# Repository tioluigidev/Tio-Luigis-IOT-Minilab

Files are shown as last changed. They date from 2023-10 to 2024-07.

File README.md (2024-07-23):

# My IOT Minilab

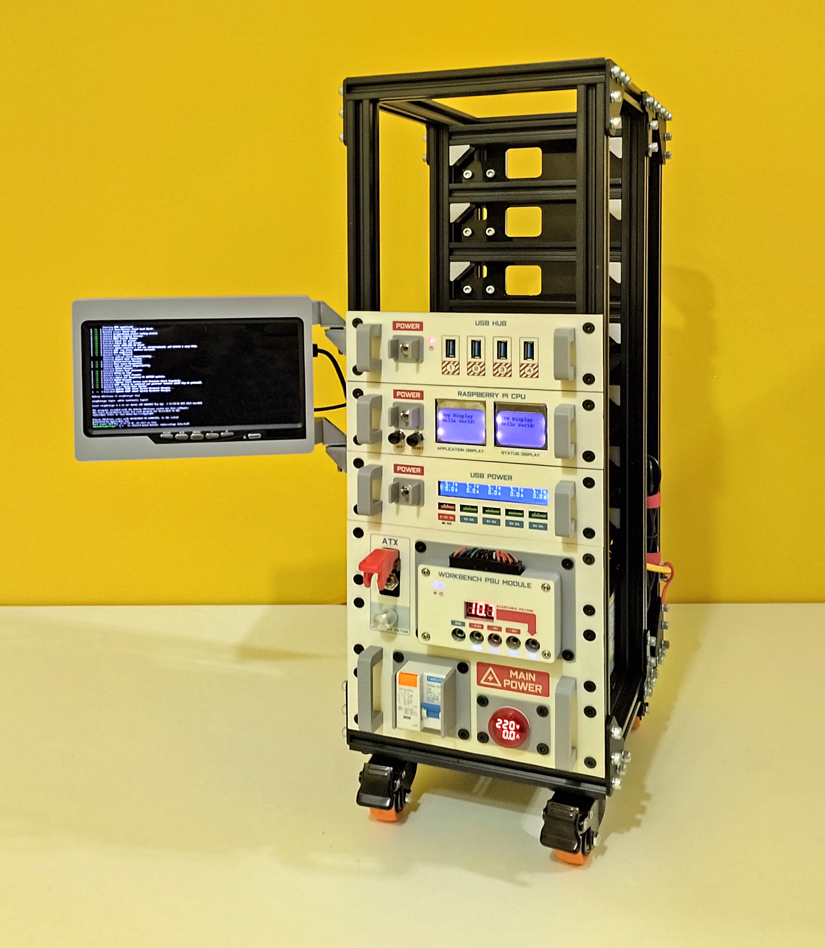
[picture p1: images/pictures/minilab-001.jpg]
Tio Luigi´s IOT Minilab


## Description

This is my IoT minilab. A platform to make projects and experiments involving the internet of things and electronics.
This is an open source project and you will find all necessary information to reproduce this project, modify it, contribute with it, etc.

I hope you enjoy it :)

## Features

- Rack mounted in a "maker style", so you can easily modify it, extend it, create new modules, etc.
- You can also use it as a workbench tool.
- ATX PSU (3.3V, 5V, 12V and adjustable voltage) for the built-in modules and for the workbench experiments and tests.
- USB PSU/charger, for those devices that uses USB power cord, inside the rack or on the workbench.
- Small CPU module with USB hub for conecting to your IOT devices (yes yes, inside the rack or on the workbench).
- It uses ready-made parts, so you don´t have to make printed circuit boards!

## Structure and Modules

|Picture|Documentation|
|---|---|
|USB Hub Module|[USB Hub Module](readme-module-usbhub.md)|
|Raspberry Pi CPU Module|[Raspberry Pi CPU Module](readme-module-rpicpu.md)|
|USB Power Module|[USB Power Module](readme-module-usbpower.md)|
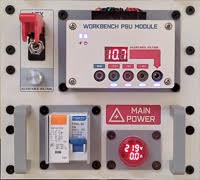
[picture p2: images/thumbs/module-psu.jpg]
PSU Module
||[PSU Module](readme-module-psu.md)|
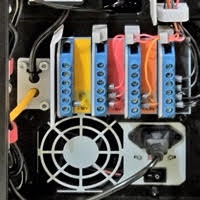
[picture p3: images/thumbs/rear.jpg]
Rear
||[Rear](readme-rear.md)|
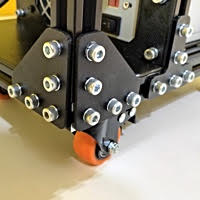
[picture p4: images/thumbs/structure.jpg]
Structure
||[Structure](readme-structure.md)|

## Extras

Some optional stuffs that may be usefull:

|Picture|Documentation|
|---|---|
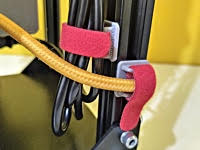
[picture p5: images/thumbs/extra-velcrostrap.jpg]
Support for velcro strap
||[Support for velcro strap](readme-extra-velcrostrap.md)|
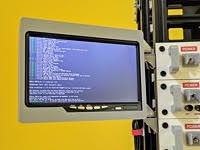
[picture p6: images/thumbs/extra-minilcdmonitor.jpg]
Mini LCD monitor
||[Mini LCD monitor](readme-extra-minilcdmonitor.md)|

## Blender Project

This minilab was designed on Blender 3D software. You can download the Blender project file [here](project/minilab.blend).
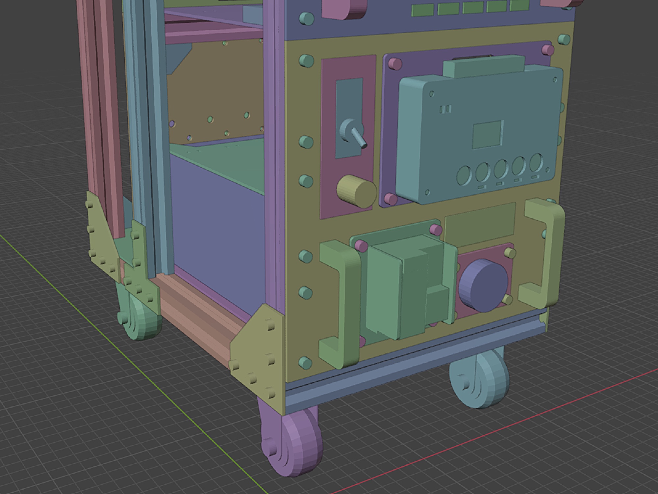
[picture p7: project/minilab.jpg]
Project


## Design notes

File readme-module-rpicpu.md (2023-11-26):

# Raspberry Pi CPU Module

## Description

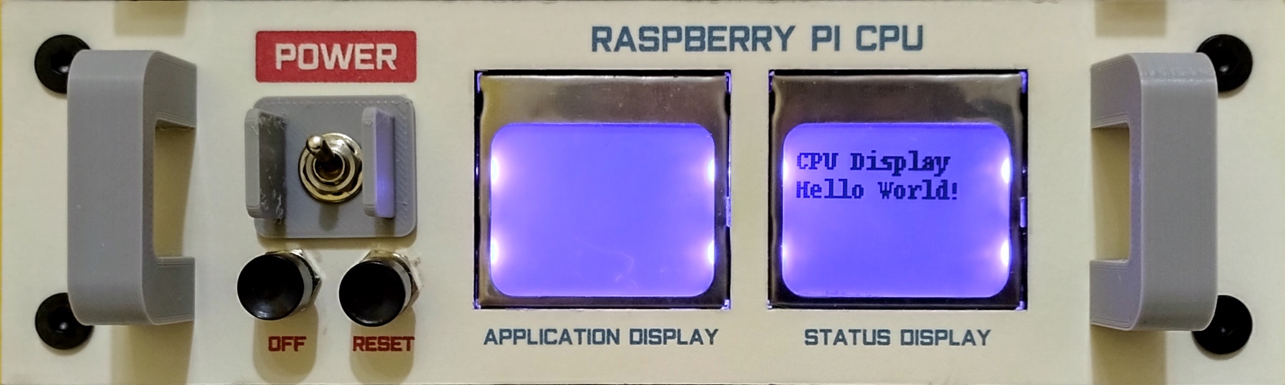
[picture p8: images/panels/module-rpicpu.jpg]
Raspberry Pi CPU Module


This module is "a brain" for the minilab. I connected 2 Nokia 5110 displays to the Raspberry Pi 4 SPI interface. One for system status and another one for application informations. I decided to use the Ultra Thin Ice Tower Cooler, because in addition to the 2 power wires, it also has a third wire through which the fan speed can be measured. I also decided to use a 400 points breadboard, for a small hacking space.

There is also two push buttons: one for RESET and another one for OFF functions. The pressing of theese buttons is handled by the "monitor.py" software in "src" directory.  

## Schematics

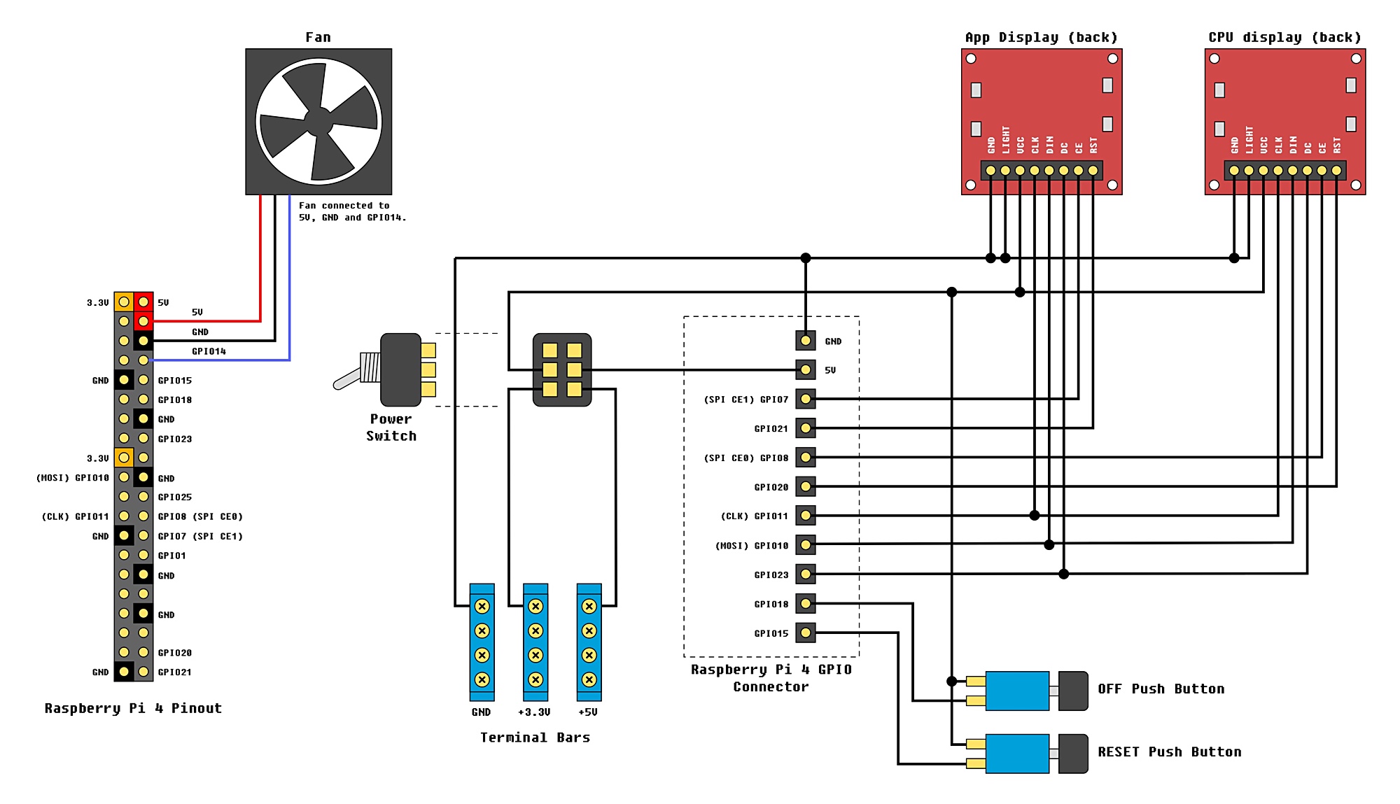
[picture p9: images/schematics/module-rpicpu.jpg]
Raspberry Pi CPU Module Schematics


For the LCD backlight control pins, you have three choices:
- Leave then unconnected, so the backlights will always be turned off,
- Connect then to the GND, so the backlights will always be turned on,
- Connect then to the GPIO 1 and 25 pins (like me), so you can control via software when turn on or off the backlights.

## 3D Printed Parts

To make the 3d printed parts, I used an Creality Ender 3 similar 3d printer. Some parts I printed with 0.8mm nozzle, just for speed gain (where aesthetics were not so important). For all the other parts, I used 0.4mm nozzle. The original editable Blender files are also included in the "3dprint" directory.

Caption|File|Prints|Nozzle|Supports|Description|
|---|---|---|---|---|---|
| 1|[rpicpu.base.stl](./3dprint/module-rpicpu/rpicpu.base.stl)|1|0.8|No|Module base.|
| 2|[rpicpu.innersupport.left.stl](./3dprint/module-rpicpu/rpicpu.innersupport.left.stl)|1|0.4|Maybe|Left inner support.|
| 3|[rpicpu.innersupport.right.stl](./3dprint/module-rpicpu/rpicpu.innersupport.right.stl)|1|0.4|Maybe|Right inner support.|
| 4|[rpicpu.panel.lcdsupport.stl](./3dprint/module-rpicpu/rpicpu.panel.lcdsupport.stl) |1|0.4|Yes|Inner support for LCD modules.|
| 5|[rpicpu.panel.front.stl](./3dprint/module-rpicpu/rpicpu.panel.front.stl) |1|0.8|Yes|Front panel for the module.|
| 6|[rpicpu.panel.powerpanel.stl](./3dprint/module-rpicpu/rpicpu.panel.powerpanel.stl)|1|0.4|No|Module switch protector.|
| 7|[rpicpu.panel.handler.stl](./3dprint/module-rpicpu/rpicpu.panel.handler.stl)|2|0.4|Maybe|Module handlers.|

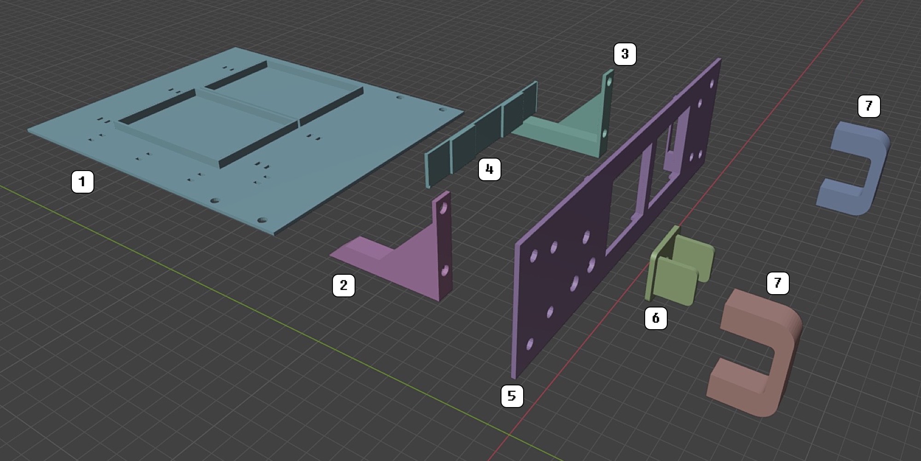
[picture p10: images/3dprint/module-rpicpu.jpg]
3D Printed Parts for Raspberry Pi CPU Module


## Paper Printed Parts

I used inkjet printer and an off-white 180g/m2 paper to make the front panel of the modules. In Brazil, this paper is known as "Color Plus 180g Marfim". To create these files, I used a software called "Graphics", that works on Mac. The original editable Graphics file for each print is in the "print" directory.

|File|Description|
|---|---|
|[print.rpicpu.panel.pdf](./print/print.rpicpu.panel.pdf)|Raspberry Pi CPU Module front panel.|

## Software

In "src" directory there is a small software in Python language, that I used to start up the LCDs and display some "Hello World" test message. To install the requirements for this software, just follow the following steps:

```bash
pip install RPi.GPIO
pip install Adafruit_GPIO
pip install pillow

sudo apt-get install git
git clone https://github.com/adafruit/Adafruit_Nokia_LCD.git
cd Adafruit_Nokia_LCD
sudo python setup.py install
cd ..

python src/monitor.py
```
PS: Don´t forget to activate the SPI interface in the Raspberry configuration tool ( raspi-config -> Interface Options -> P4 SPI -> Enable it).

If you want that this software is automatically executed on boot, just modify the "/etc/rc.local" adding the following line, where "path-to-src" is the complete path to the src/monitor.py file:

```bash
python path-to-src/monitor.py
```

## Shopping List

Qty|Description|
|---|---|
| 1 | Raspberry Pi board.|
| 1 | Ice Cube Cooler for Raspberry Pi (see Pictures). I found mine in [this link](https://pt.aliexpress.com/item/1005004647625855.html).|
| 2 | Nokia 5110 LCD displays (see Pictures).|
| 1 | 400 points breadboard (see Pictures).|
| 1 | Kit with 40 female-male jumpers 10cm min. length (see pictures).|
| 1 |Margirius lever microswitch bipolar with 2 positions (on/off).|
| 1 meter|0.30mm black wire.|
| 1 meter|0.30mm red wire.|
| 1 meter|0.30mm orange wire.|
| 1 meter|0.30mm red wire.|
| 1 meter|0.30mm any color wire, to connect the OFF push botton to the breadboard.|
| 1 meter|0.30mm any color wire, to connect the RESET push botton to the breadboard.|
| 15 ~ 20|Nylon cable ties.|
| 4 |Allen Bolt M5x6 Cylindrical Head.|
| 8 |Allen Bolt M5x6 Flat Head.|
| 4 |Hammer Nut M5.|
| 1 |Thick paper sheet (if you want to print the panel).|
| ~ 125g | PLA 3D print filament.|

## Nuts and Bolts

Picture|Description|
|---|---|
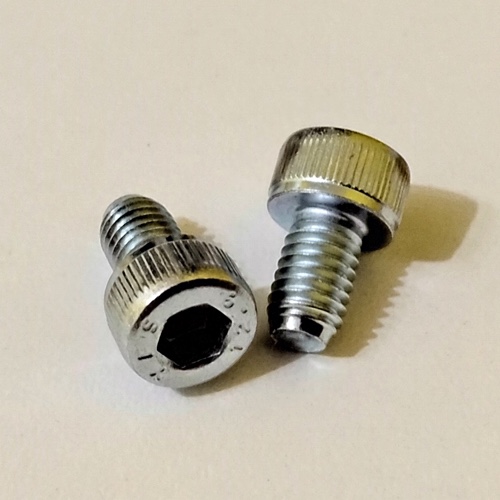
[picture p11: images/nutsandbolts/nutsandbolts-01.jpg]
||Allen Bolt M5x6 Cylindrical Head (5mm on diameter, 6mm on length)|
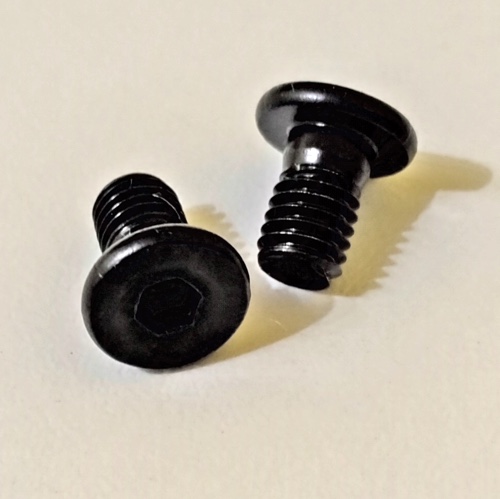
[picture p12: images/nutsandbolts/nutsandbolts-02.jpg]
||Allen Bolt M5x6 Flat Head (5mm on diameter, 6mm on length)|
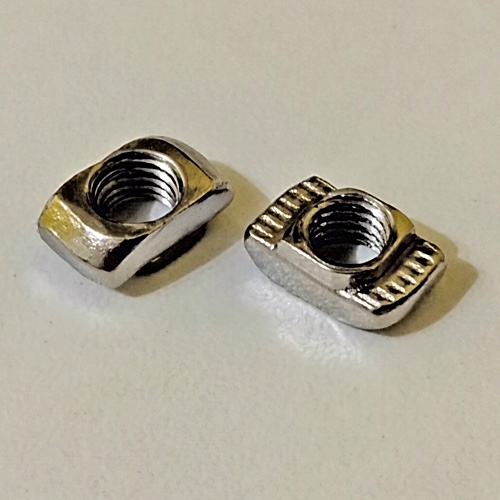
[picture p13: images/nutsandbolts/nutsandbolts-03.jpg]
||Hammer Nut M5 (for 5mm diameter bolts)|

## Pictures

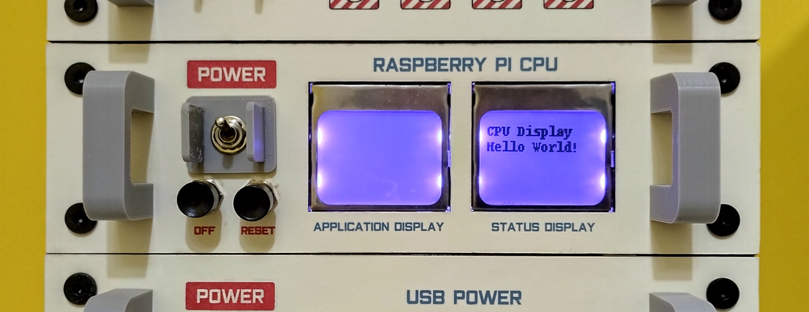
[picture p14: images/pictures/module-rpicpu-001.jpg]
Raspberry Pi CPU Module (panel)


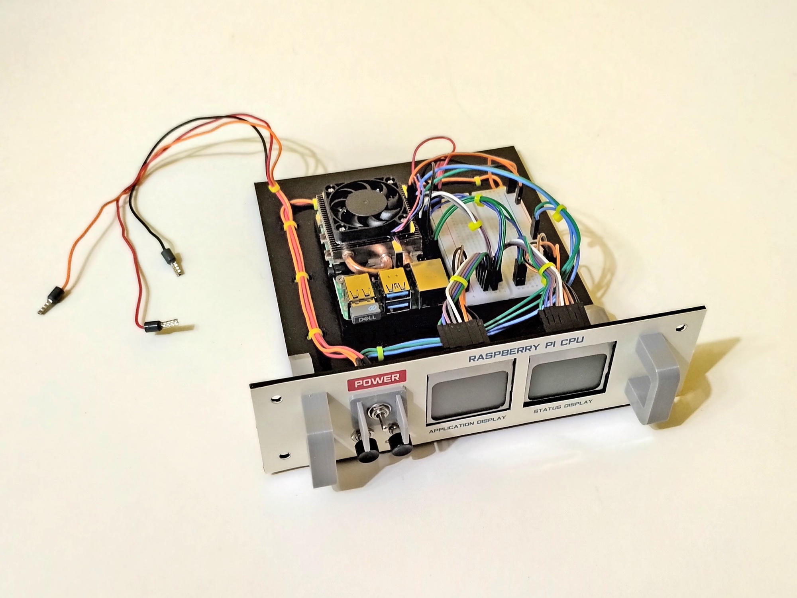
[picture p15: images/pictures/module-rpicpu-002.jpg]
Raspberry Pi CPU Module (whole)


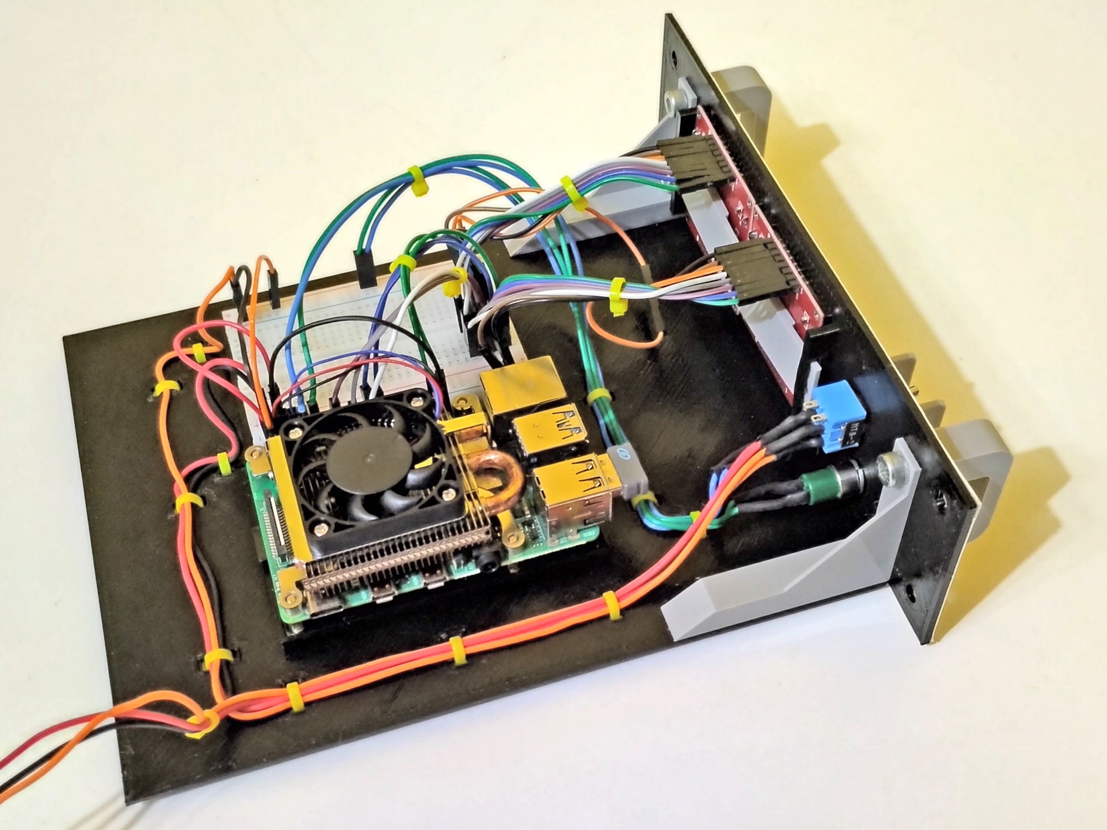
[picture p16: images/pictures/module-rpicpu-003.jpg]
Raspberry Pi CPU Module (left)


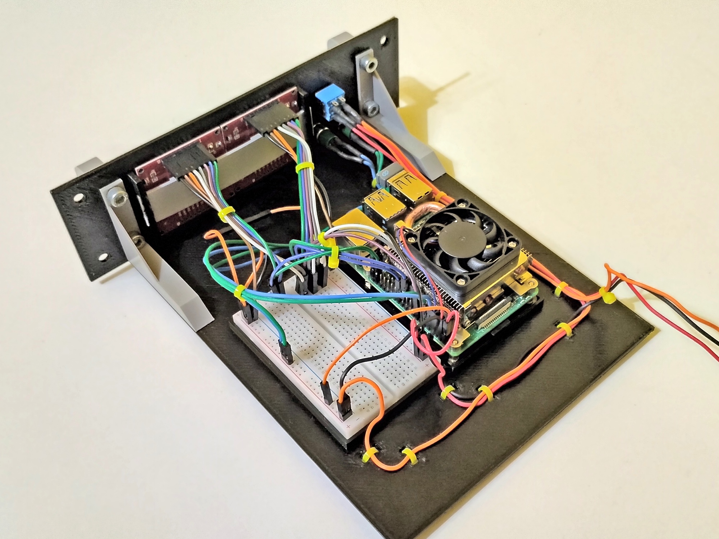
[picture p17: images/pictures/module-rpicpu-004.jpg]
Raspberry Pi CPU (right)


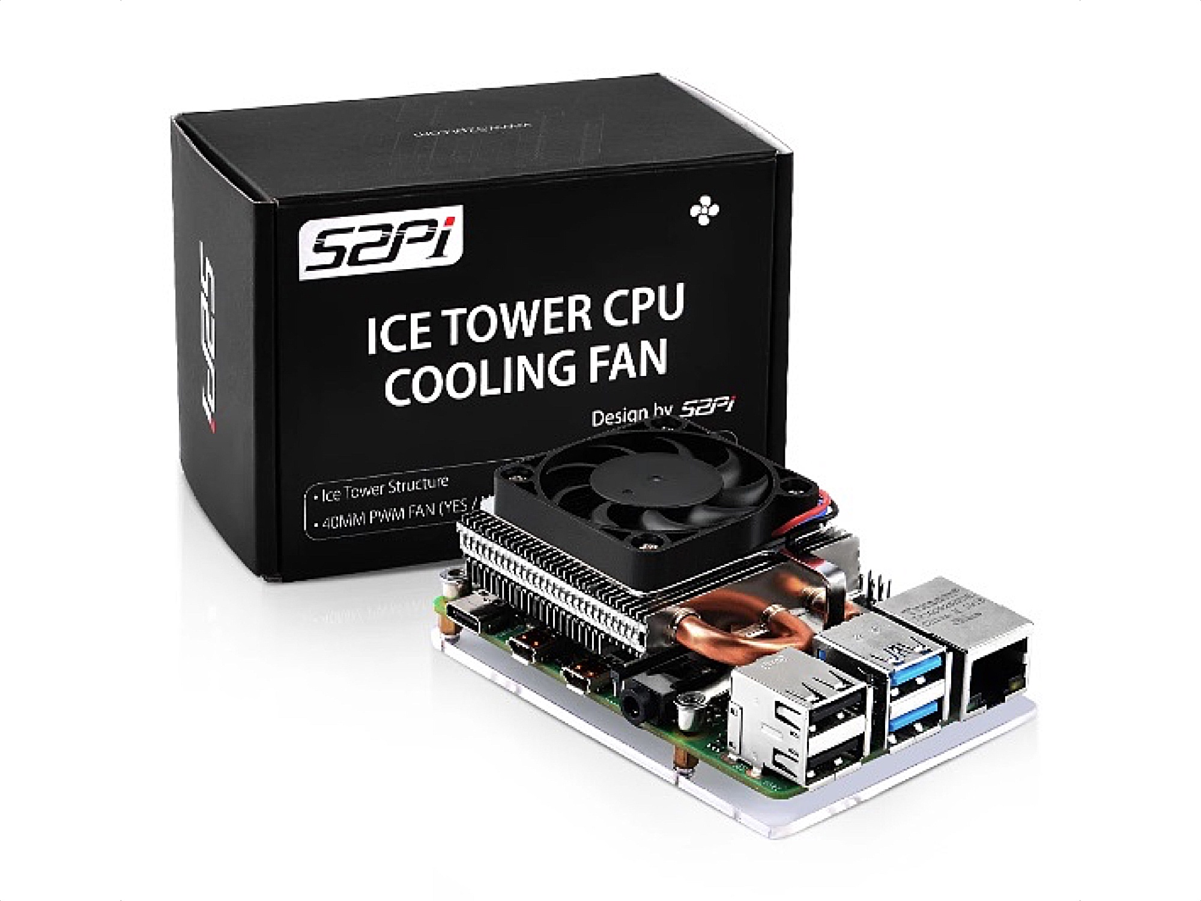
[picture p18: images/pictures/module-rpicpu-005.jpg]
Raspberry Pi CPU (Raspberry Pi and Cooler)


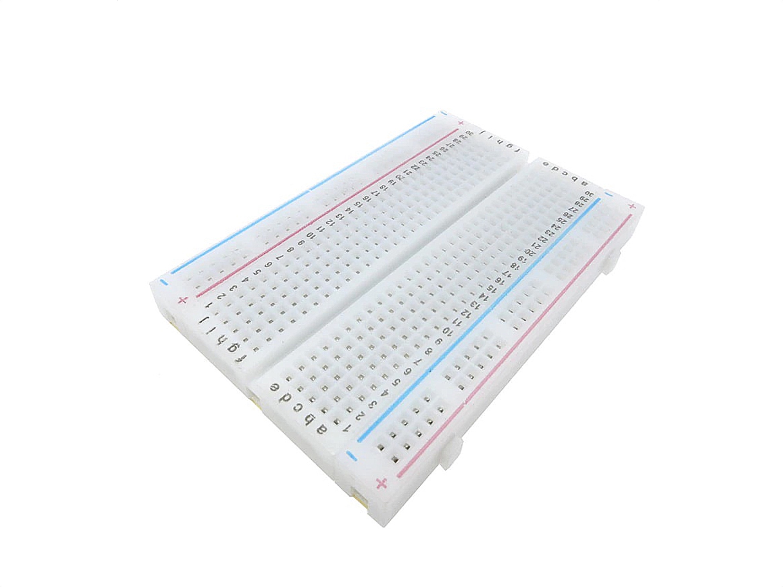
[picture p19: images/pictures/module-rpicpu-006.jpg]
400 Points Breadboard


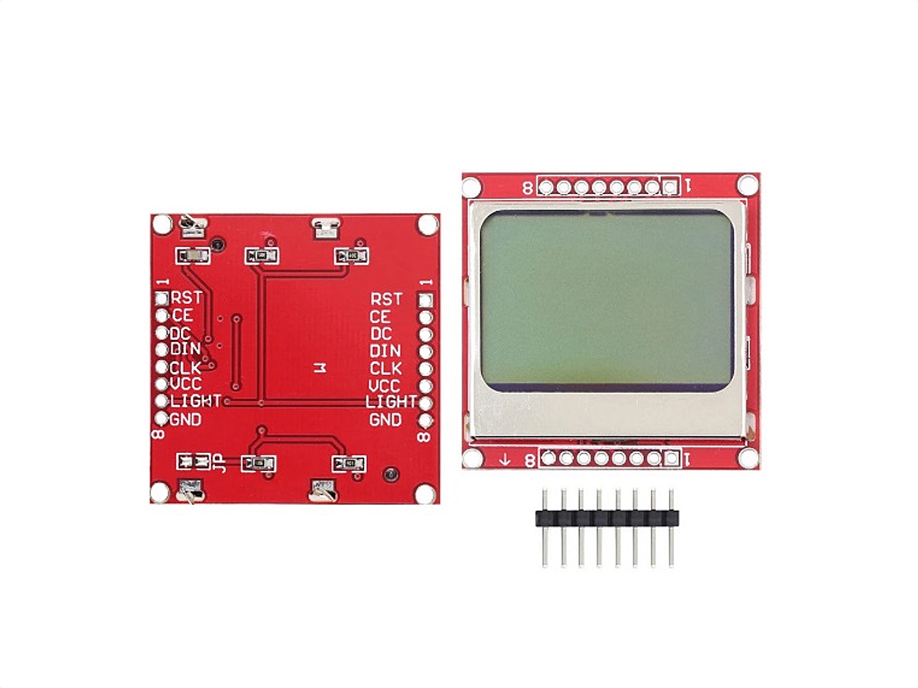
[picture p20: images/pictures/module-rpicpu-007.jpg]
Nokia 5110 LCD Display


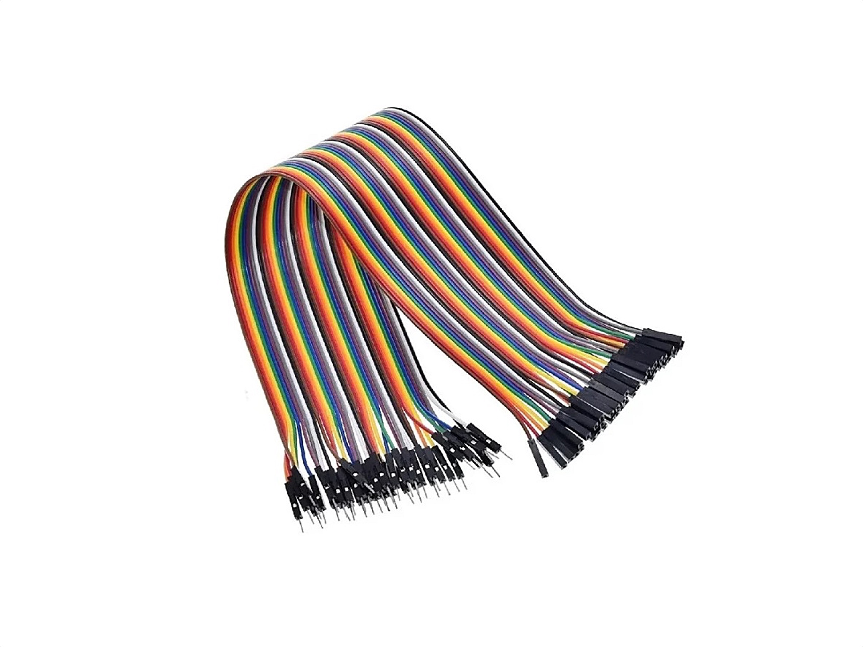
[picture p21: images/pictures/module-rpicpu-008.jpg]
Kit 40 jumpers female-male (min. 10 cm)


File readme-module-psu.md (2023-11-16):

# PSU Module

## Description

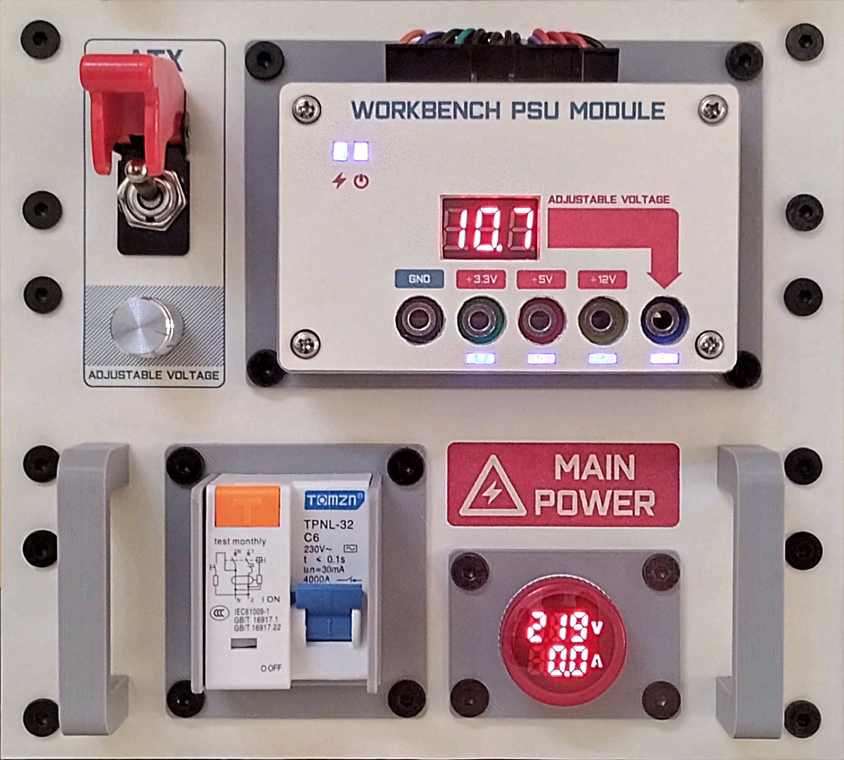
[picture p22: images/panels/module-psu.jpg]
PSU Module


The PSU (Power Supply Unity) Module is responsible to power up all the system. It´s the only module designed to be fixed (not so easily removable). The main power switch is a 6A circuit breaker. In my project, I used a circuit breaker with residual current protection, to prevent electrical shock. There is also a power meter with a double display, for voltage and current measuring. The main power line ends in a power strip, with 4 electrical outlets.

Connected to this power strip, there is an ATX Power Supply. I used a 250W retail model. This ATX PSU powers the 4 terminal bars at the rear part of the rack. These terminal bars are used to power all the small circuits and IOT devices that uses 3.3V, 5V and/or 12V power.

The ATX PSU also powers a Workbench Module, used to provide voltage to workbench projects and experiments. Connected to this module, there is a Power Switch, that starts up the ATX PSU and a potentiometer for adustable voltage output, provided by the workbench module too. 

## Schematics

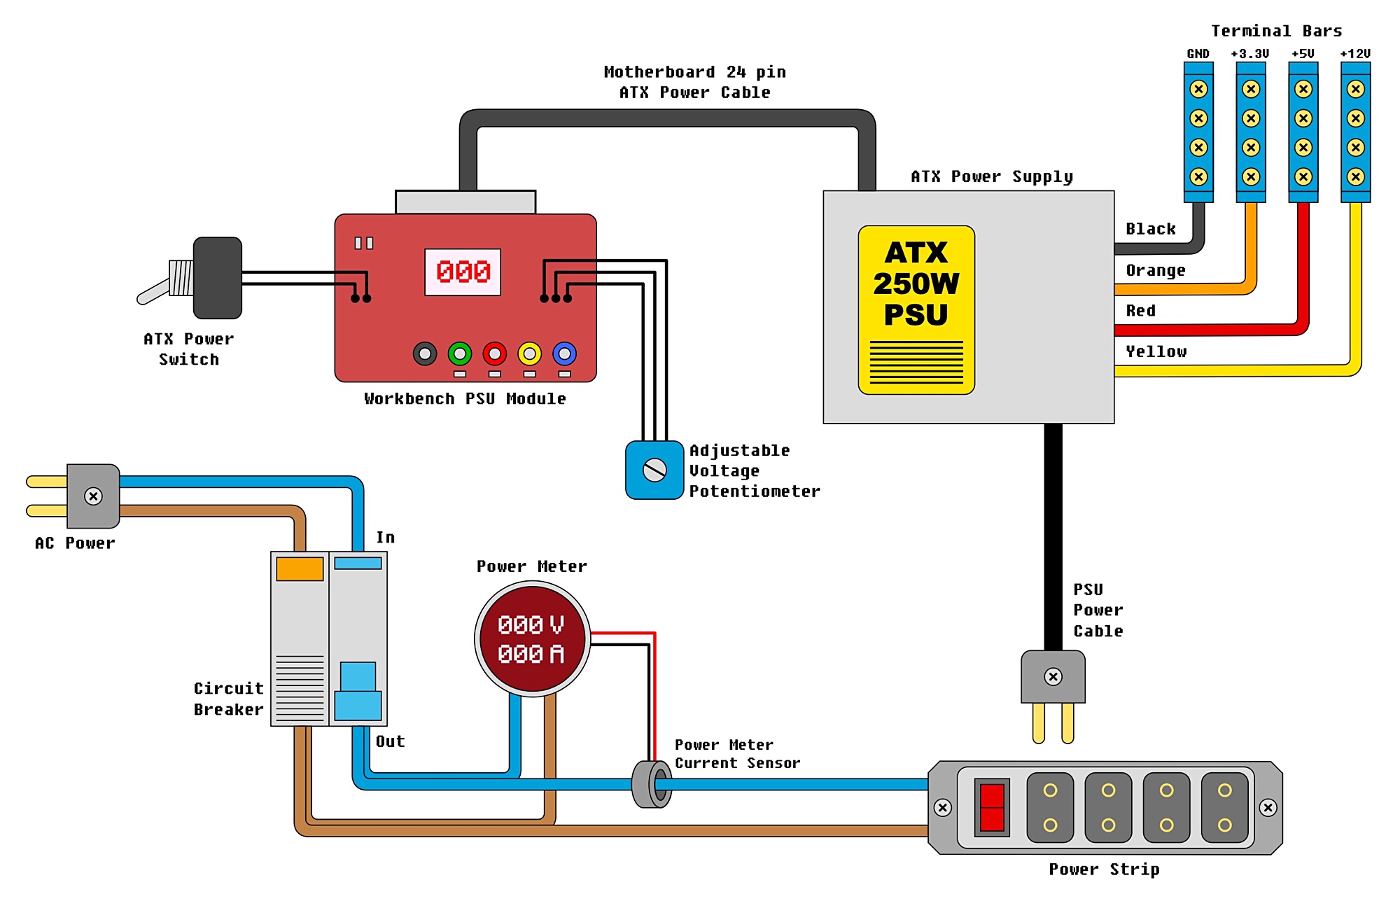
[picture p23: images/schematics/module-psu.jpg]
PSU Module Schematics


## 3D Printed Parts

To make the 3d printed parts, I used an Creality Ender 3 similar 3d printer. Some parts I printed with 0.8mm nozzle, just for speed gain (where aesthetics were not so important). For all the other parts, I used 0.4mm nozzle. The original editable Blender files are also included in the "3dprint" directory.

Caption|File|Prints|Nozzle|Supports|Description|
|---|---|---|---|---|---|
| 1|[psu.base.stl](./3dprint/module-psu/psu.base.stl)|1|0.8|No|Module base, wich supports the ATX PSU.|
| 2|[psu.cableguide.stl](./3dprint/module-psu/psu.cableguide.stl)|1|0.8|Maybe|Inner cable guide. I didn't use supports.|
| 3|[psu.circuitbreakersupport.stl](./3dprint/module-psu/psu.circuitbreakersupport.stl)|1|0.8|No|Circuit breaker support. Necessary to keep the circuit breaker in the correct position and tight attached to the front panel.|
| 4|[psu.potentiometersupport.stl](./3dprint/module-psu/psu.panel.potentiometersupport.stl) |1|0.4|Yes|Adjustable voltage potentiometer support. Necessary to keep the potentiometer in the correct position and tight attached to the front panel.|
| 5|[psu.panel.front.stl](./3dprint/module-psu/psu.panel.front.stl)                 |1|0.8|No|Front panel, where all other panel components are attached to.|
| 6|[psu.panel.modulecover1.stl](./3dprint/module-psu/psu.panel.modulecover1.stl)   |1|0.4|No|Workbench module base.|
| 7|[psu.panel.modulecover2.stl](./3dprint/module-psu/psu.panel.modulecover2.stl)   |1|0.4|No|Workbench module cover.|
| 8|[psu.panel.circuitbreakerpanel.stl](./3dprint/module-psu/psu.panel.circuitbreakerpanel.stl)|1|0.4|No|Circuit breaker front protector.|
| 9|[psu.panel.meterpanel.stl](./3dprint/module-psu/psu.panel.meterpanel.stl) |1|0.4|No|Power meter front base.|
|10|[psu.panel.handler.stl](./3dprint/module-psu/psu.panel.handler.stl)       |2|0.4|Maybe|Left and right module handler. I used supports.|

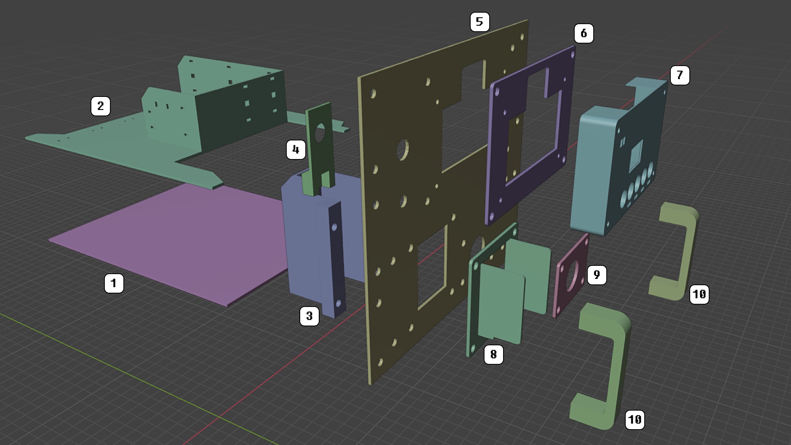
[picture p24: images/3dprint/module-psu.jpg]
3D Printed Parts for PSU Module


## Paper Printed Parts

I used inkjet printer and an off-white 180g/m2 paper to make the front panel of the modules. In Brazil, this paper is known as "Color Plus 180g Marfim". To create these files, I used a software called "Graphics", that works on Mac. The original editable Graphics file for each print is in the "print" directory.

|File|Description|
|---|---|
|[print.psu.panel.pdf](./print/print.psu.panel.pdf)|PSU Module front panel.|
|[print.psu.panel.module.pdf](./print/print.psu.panel.module.pdf)|Workbench PSU Module panel.|
|[print.rear.labels.pdf](./print/print.rear.labels.pdf)|Rear Terminal Bars labels.|

## Shopping List

Qty|Description|
|---|---|
| 1|ATX power supply. 250W is far enough.|
| 1|ATX PSU breakout module (see pictures).|
| 1|Power strip with 4 outlets.|
| 1|6A circuit breaker. I uded a Tomzn C6 model.|
| 1|Voltage and current meter (see pictures).|
| 4|Terminal bars with 6 terminals each. I found mine in [this link](https://pt.aliexpress.com/item/1005004186912405.html).
| 1|Power plug.|
| 1|Power Switch. I used a margirius switch with protection cover.|
| 1|100K linear potentiometer (only if your breakout module came with a logarithmic one).|
| 1 meter|2.5mm blue wire, for internal wiring. Maybe you don´t need this, if you use the power strip cord.|
| 1 meter|2.5mm brown wire, for internal wiring. Maybe you don´t need this, if you use the power strip cord.|
| 1 ~ 2 meters|0.30mm wire, for connect the ATX Power Switch and the Potentiometer to the ATX breakout module.|
| 1 ~ 2 meters|Main power cord with plug.|
| 20 ~ 30|Nylon cable ties.|
|  8|Allen Bolt M5x6 Cylindrical Head.|
| 24|Allen Bolt M5x6 Flat Head.|
|  4|Spring Washer 5mm.|
| 12|Hammer Nut M5.|
|  8|Allen Bolt M3x20 with washer and pressure bolt.|
| ~ 320g | PLA 3D print filament. |

## Nuts and Bolts

Picture|Description|
|---|---|
|PSU Module|Allen Bolt M5x6 Cylindrical Head (5mm on diameter, 6mm on length)|
|PSU Module|Allen Bolt M5x6 Flat Head (5mm on diameter, 6mm on length)|
|PSU Module|Hammer Nut M5 (for 5mm diameter bolts)|
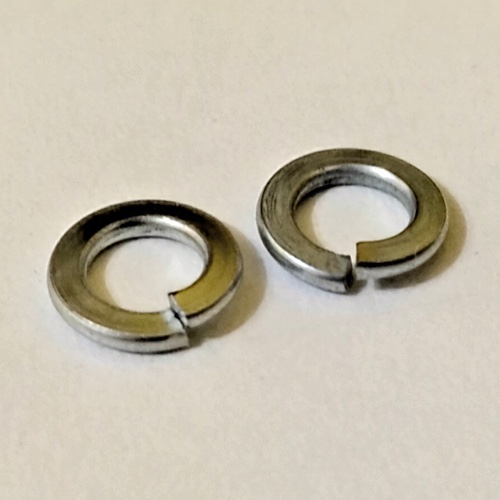
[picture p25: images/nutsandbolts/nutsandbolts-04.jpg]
||Spring Washer 5mm|
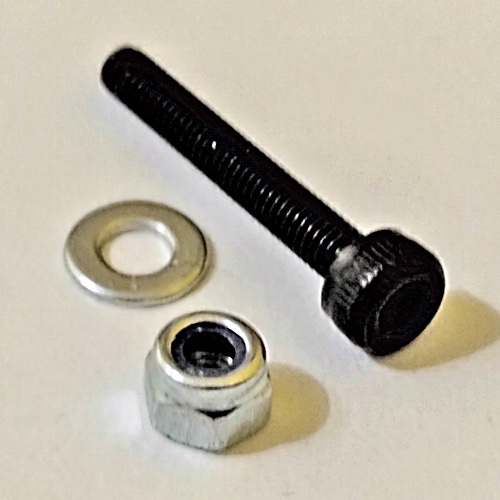
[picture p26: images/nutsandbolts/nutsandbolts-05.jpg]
||Allen Bolt M3x20 (3mm on diameter, 20mm on lenght) with washer and pressure bolt.|

## Pictures

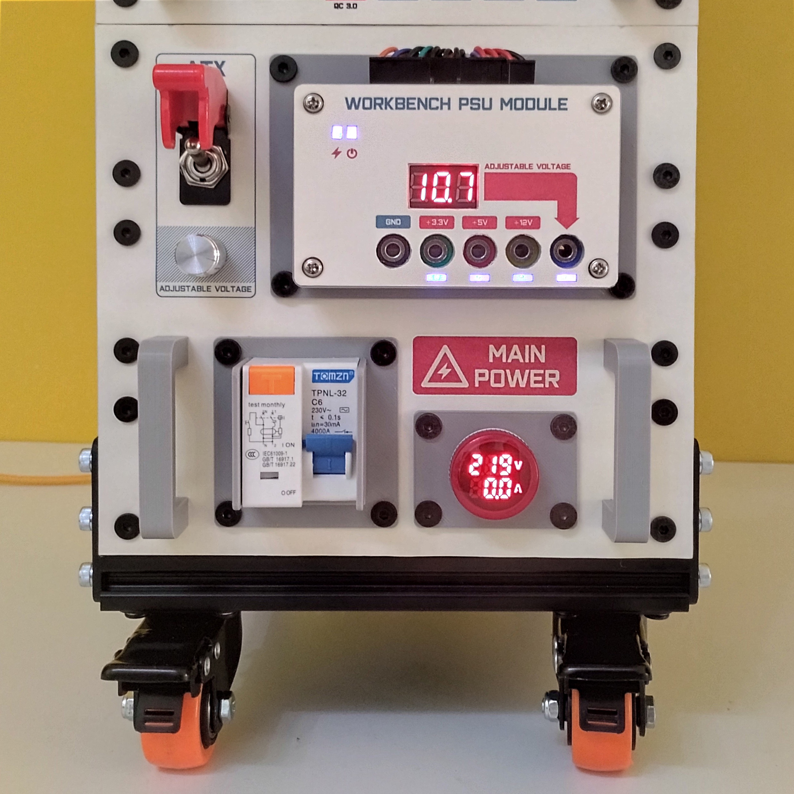
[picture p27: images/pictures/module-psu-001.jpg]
PSU Module


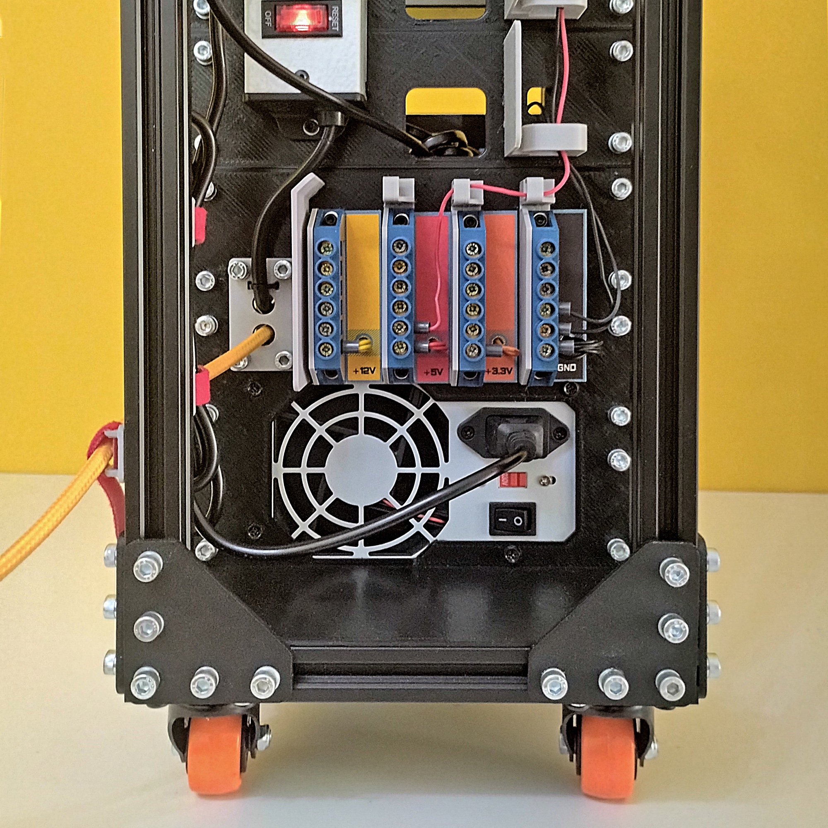
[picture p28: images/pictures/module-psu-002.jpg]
PSU Module (rear)


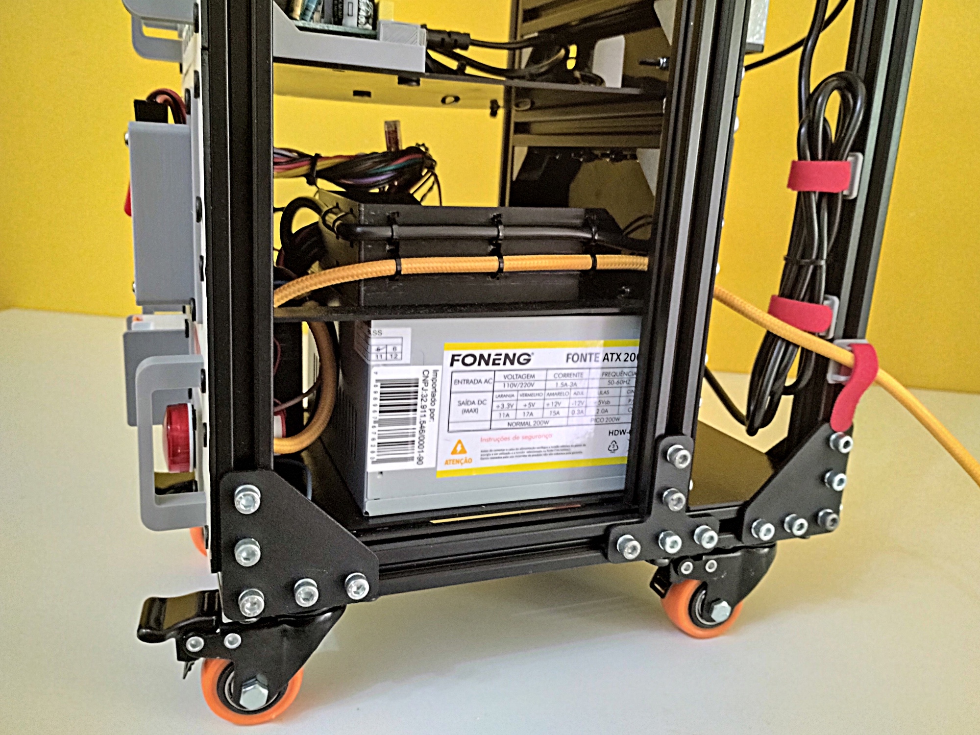
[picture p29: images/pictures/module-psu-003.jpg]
PSU Module (inside right)


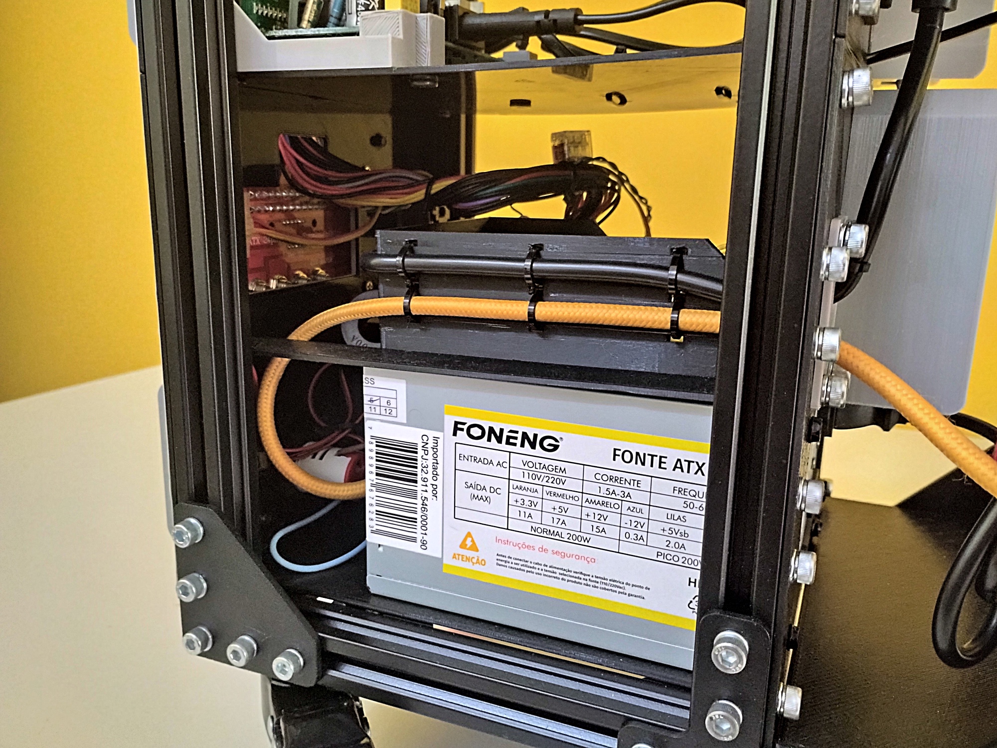
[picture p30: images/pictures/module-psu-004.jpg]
PSU Module (inside right)


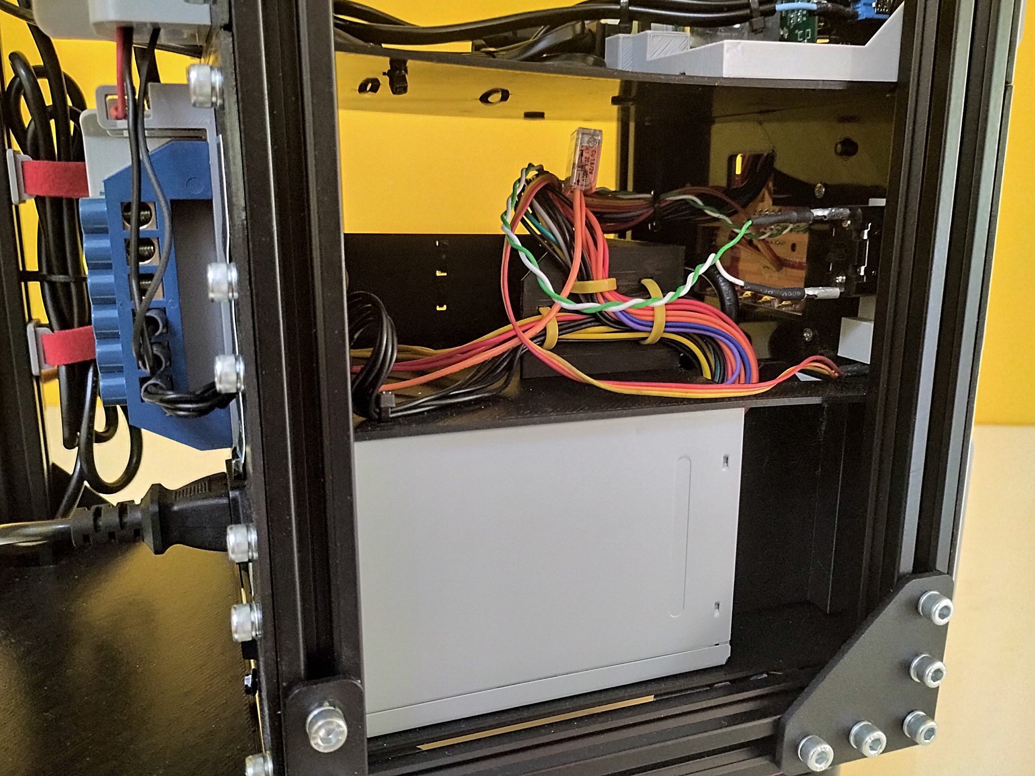
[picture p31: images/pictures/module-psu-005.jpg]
PSU Module (inside left)


PSU Module (ATX Breakout Module)

ATX Breakout Module, as sold

Circuit Breaker

Meter

Terminal Bar

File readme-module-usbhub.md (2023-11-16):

# USB Hub Module

## Description

PSU Module

This module is intended to provide USB connectivity from the CPU to other devices. These devices may be inside the minilab or outside (on a workbench, for example). I did´t built it from stratch. Instead, I used an USB hub with 4 ports. I chose this model because it has the USB ports well away from each other, and this is an important detail for a project I want to do in a near future.

## Schematics

USB Hub Module Schematics

## 3D Printed Parts

To make the 3d printed parts, I used an Creality Ender 3 similar 3d printer. Some parts I printed with 0.8mm nozzle, just for speed gain (where aesthetics were not so important). For all the other parts, I used 0.4mm nozzle. The original editable Blender files are also included in the "3dprint" directory.

Caption|File|Prints|Nozzle|Supports|Description|
|---|---|---|---|---|---|
| 1|[usbhub.base.stl](./3dprint/module-usbhub/usbhub.base.stl)|1|0.8|No|Module base.|
| 2|[usbhub.innersupport.left.stl](./3dprint/module-usbhub/usbhub.innersupport.left.stl)|1|0.4|Maybe|Left inner support for the usb hub circuit.|
| 3|[usbhub.innersupport.right.stl](./3dprint/module-usbhub/usbhub.innersupport.right.stl)|1|0.4|Maybe|Right inner support for the usb hub circuit.|
| 4|[usbhub.innersupport.middle.stl](./3dprint/module-usbhub/usbhub.innersupport.middle.stl) |1|0.4|No|Main inner support for the usb hub circuit.|
| 5|[usbhub.panel.front.stl](./3dprint/module-usbhub/usbhub.panel.front.stl) |1|0.8|No|Front panel for the module.|
| 6|[usbhub.panel.powerpanel.stl](./3dprint/module-usbhub/usbhub.panel.powerpanel.stl)|1|0.4|No|Module switch protector.|
| 7|[usbhub.panel.handler.stl](./3dprint/module-usbhub/usbhub.panel.handler.stl)|2|0.4|Maybe|Module handlers.|

3D Printed Parts for PSU Module

## Paper Printed Parts

I used inkjet printer and an off-white 180g/m2 paper to make the front panel of the modules. In Brazil, this paper is known as "Color Plus 180g Marfim". To create these files, I used a software called "Graphics", that works on Mac. The original editable Graphics file for each print is in the "print" directory.

|File|Graphics File|Description|
|---|---|---|
|[print.usbhub.panel.pdf](./print/print.usbhub.panel.pdf)|USB Hub Module front panel.|

## Shopping List

Qty|Description|
|---|---|
| 1 | USB Hub. I found mine in [this link](https://pt.aliexpress.com/item/1005001774949015.html). |
| 1 |Margirius lever microswitch bipolar with 2 positions (on/off).|
| 5 ~ 8|Nylon cable ties.|
| 4 |Allen Bolt M5x6 Cylindrical Head.|
| 8 |Allen Bolt M5x6 Flat Head.|
| 4 |Hammer Nut M5.|
| 1 |Thick paper sheet (if you want to print the panel).|
| ~ 125g | PLA 3D print filament.|

## Nuts and Bolts

Picture|Description|
|---|---|
|PSU Module|Allen Bolt M5x6 Cylindrical Head (5mm on diameter, 6mm on length)|
|PSU Module|Allen Bolt M5x6 Flat Head (5mm on diameter, 6mm on length)|
|PSU Module|Hammer Nut M5 (for 5mm diameter bolts)|

## Pictures

USB Hub Module (panel)

USB Hub Module (whole)

USB Hub Module (right)

USB Hub Module (left)

USB Hub

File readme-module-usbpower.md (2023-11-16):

# USB Power Module

## Description

PSU Module

This module is intended to power up the devices with USB power cords. These devices may be inside the minilab rack mount or outside (on a workbench, for example). I did´t built it from stratch. Instead, I used an USB charger with 4 ports and an extra port with Quick Charge 3.0 standard capabilities.

## Schematics

USB Power Module Schematics
Important: It´s necessary to connect any GND point in the Charger to the GND terminal bar at the rear of the rack.

## 3D Printed Parts

To make the 3d printed parts, I used an Creality Ender 3 similar 3d printer. Some parts I printed with 0.8mm nozzle, just for speed gain (where aesthetics were not so important). For all the other parts, I used 0.4mm nozzle. The original editable Blender files are also included in the "3dprint" directory.

Caption|File|Prints|Nozzle|Supports|Description|
|---|---|---|---|---|---|
| 1|[usbpower.base.stl](./3dprint/module-usbpower/usbpower.base.stl)|1|0.8|No|Module base.|
| 2|[usbpower.innersupport.left.stl](./3dprint/module-usbpower/usbpower.innersupport.left.stl)|1|0.4|Yes|Left inner support for the usb charger circuit.|
| 3|[usbpower.innersupport.right.stl](./3dprint/module-usbpower/usbpower.innersupport.right.stl)|1|0.4|Yes|Right inner support for the usb charger circuit.|
| 4|[usbpower.panel.front.stl](./3dprint/module-usbpower/usbpower.panel.front.stl) |1|0.8|No|Front panel for the module.|
| 5|[usbpower.panel.powerpanel.stl](./3dprint/module-usbpower/usbpower.panel.powerpanel.stl)|1|0.4|No|Power switch protector.|
| 6|[usbpower.panel.handler.stl](./3dprint/module-usbpower/usbpower.panel.handler.stl)|2|0.4|Maybe|Module handlers.|

3D Printed Parts for PSU Module

## Paper Printed Parts

I used inkjet printer and an off-white 180g/m2 paper to make the front panel of the modules. In Brazil, this paper is known as "Color Plus 180g Marfim". To create these files, I used a software called "Graphics", that works on Mac. The original editable Graphics file for each print is in the "print" directory.

|File|Description|
|---|---|
|[print.usbpower.panel.pdf](./print/print.usbpower.panel.pdf)|USB Power Module front panel.|

## Shopping List

Qty|Description|
|---|---|
|  1| USB Charger. I found mine in [this link](https://pt.aliexpress.com/item/32979578903.html), but I don´t know if "Tongdaytech" is the brand or the name of the shop. |
| 1 |Margirius lever microswitch bipolar with 2 positions (on/off).|
| 1 meter|0.30mm black wire.|
| 5 ~ 10|Nylon cable ties.|
| 10|Allen Bolt M5x6 Cylindrical Head.|
| 4 |Allen Bolt M5x6 Flat Head.|
| 4 |Hammer Nut M5.|
| 1 |Thick paper sheet (if you want to print the panel).|
| ~ 130g | PLA 3D print filament.|

## Nuts and Bolts

Picture|Description|
|---|---|
|PSU Module|Allen Bolt M5x6 Cylindrical Head (5mm on diameter, 6mm on length)|
|PSU Module|Allen Bolt M5x6 Flat Head (5mm on diameter, 6mm on length)|
|PSU Module|Hammer Nut M5 (for 5mm diameter bolts)|

## Pictures

USB Power Module

USB Power Module (whole)

USB Power Module (inside right)

USB Power Module (inside left)

USB Power Charger

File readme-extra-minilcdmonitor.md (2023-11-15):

# Mini LCD Monitor Support

## Description

PSU Module

Support for this model of mini LCD monitor. It can be useful for maintenance activities on the Raspberry Pi, for example.

## 3D Printed Parts

To make the 3d printed parts, I used an Creality Ender 3 similar 3d printer. Some parts I printed with 0.8mm nozzle, just for speed gain (where aesthetics were not so important). For all the other parts, I used 0.4mm nozzle. The original editable Blender files are also included in the "3dprint" directory.

File|Prints|Nozzle|Supports|Description|
|---|---|---|---|---|
|[extra-minilcdmonitor-front.stl](./3dprint/extra-minilcdmonitor/extra-minilcdmonitor-front.stl)|1|0.4|No|Front cover.|
|[extra-minilcdmonitor-back.stl](./3dprint/extra-minilcdmonitor/extra-minilcdmonitor-back.stl)|1|0.4|No|Back cover.|
|[extra-minilcdmonitor-spacer.stl](./3dprint/extra-minilcdmonitor/extra-minilcdmonitor-spacer.stl)|4|0.4|No|Spacer.|

## Shopping List

Qty|Description|
|---|---|
| 1|Mini LCD Monitor (see pictures).|
| 4|20x20x17mm corner for V-slot or T-slot.|
| 1 ~ 3|Nylon cable ties.|
| 4|Allen Bolt M5x6 Flat Head.|
| 6|Spring Washer 5mm.|
| 2 ~ 4|Washer 5mm.|
| 2|Hammer Nut M5.|
| 2|Allen Bolt M5x40 (5mm on diameter, 40mm on length).|
| ~ 130g | PLA 3D print filament. |

## Nuts and Bolts

Picture|Description|
|---|---|
|PSU Module|Allen Bolt M5x6 Cylindrical Head (5mm on diameter, 6mm on length)|
|PSU Module|Allen Bolt M5x6 Flat Head (5mm on diameter, 6mm on length)|
|PSU Module|Hammer Nut M5 (for 5mm diameter bolts)|
|PSU Module|Spring Washer 5mm|

## Pictures

PSU Module

PSU Module

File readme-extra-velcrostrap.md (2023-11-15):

# Extra - Velcro Strap Support

## Description

Velcro Strap Support

Support for velcro strap, for a better cable organizing.

## 3D Printed Parts

To make the 3d printed parts, I used an Creality Ender 3 similar 3d printer. Some parts I printed with 0.8mm nozzle, just for speed gain (where aesthetics were not so important). For all the other parts, I used 0.4mm nozzle. The original editable Blender files are also included in the "3dprint" directory.

File|Prints|Nozzle|Supports|Description|
|---|---|---|---|---|
|[extra-velcrostrap.stl](./3dprint/extra-velcrostrap/extra-velcrostrap.stl)|1|0.4|Yes|Velcro Strap Support.|

## Shopping List

For each velcro strap support, you will need:

Qty|Description|
|---|---|
| 1|Velcro strap 12mm wide.|
| 1|Allen Bolt M5x6 Flat Head.|
| 1|Spring Washer 5mm.|
| 1|Hammer Nut M5.|
| ~ 2g | PLA 3D print filament. |

## Nuts and Bolts

Picture|Description|
|---|---|
|PSU Module|Allen Bolt M5x6 Flat Head (5mm on diameter, 6mm on length)|
|PSU Module|Hammer Nut M5 (for 5mm diameter bolts)|
|PSU Module|Spring Washer 5mm|

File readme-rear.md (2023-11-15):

# Rear

## Description

This is the rear part of the minilab rack, where are all the module´s back cover and where the power strip are fixed on. 

## 3D Printed Parts

To make the 3d printed parts, I used an Creality Ender 3 similar 3d printer. Some parts I printed with 0.8mm nozzle, just for speed gain (where aesthetics were not so important). For all the other parts, I used 0.4mm nozzle. The original editable Blender files are also included in the "3dprint" directory.

Caption|File|Prints|Nozzle|Supports|Description|
|---|---|---|---|---|---|
| 1|[rear.baycover60mm.stl](./3dprint/rear/rear.baycover60mm.stl)|6|0.8|No|Bay cover for 60mm modules.|
| 2|[rear.baycover.psu.stl](./3dprint/rear/rear.baycover.psu.stl)|1|0.8|No|Bay cover for PSU module.|
| 3|[rear.cableguide.model4.stl](./3dprint/rear/rear.cableguide.model4.stl)|6|0.4|Maybe|Cable guide for 60mm modules.|
| 4|[psu.cableguide.model1.stl](./3dprint/rear/rear.cableguide.model1.stl) |1|0.4|No|Cable guide for PSU and power strip power cables.|
| 5|[psu.cableguide.model2.stl](./3dprint/rear/rear.cableguide.model2.stl) |1|0.4|Maybe|Cable guide for 12V terminal bar.|
| 6|[psu.cableguide.model3.stl](./3dprint/rear/rear.cableguide.model3.stl) |2|0.4|Maybe|Cable guide for 5V and 3.3V terminal bars.|
| 7|[psu.cableguide.model4.stl](./3dprint/rear/rear.cableguide.model4.stl) |1|0.4|Maybe|Cable guide for GND terminal bar.|
| 8|[psu.bottomcover.stl](./3dprint/rear/rear.bottomcover.stl)|1|0.8|No|Rear bottom cover.|

3D Printed Parts for PSU Module

## Shopping List

Qty|Description|
|---|---|
| 1|Power strip with at least 4 power plugs.|
| 1 ~ 3|Nylon cable ties.|
| 52|Allen Bolt M5x6 Cylindrical Head.|
| 36|Spring Washer 5mm.|
| 36|Hammer Nut M5.|
|  2|Allen Bolt M3x20 with washer and pressure bolt, to fix the power strip to the bay covers.|
| ~ 310g | PLA 3D print filament. |

## Nuts and Bolts

Picture|Description|
|---|---|
|PSU Module|Allen Bolt M5x6 Cylindrical Head (5mm on diameter, 6mm on length)|
|PSU Module|Hammer Nut M5 (for 5mm diameter bolts)|
|PSU Module|Spring Washer 5mm|
|PSU Module|Allen Bolt M3x20 (3mm on diameter, 20mm on lenght) with washer and pressure bolt.|

## Pictures

Rear (PSU Module)
Rear (PSU Module)
Rear (PSU Module)

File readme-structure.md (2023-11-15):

# Structure

## Description

This is all the metal parts and casters that forms the rack structure. 

## Schematics

Structure Parts

Square size of the grid below = 1cm:

Structure Parts
Structure Parts
Structure Parts
Structure Parts
Structure Parts

## Shopping List

Qty|Description|
|---|---|
| 6|540mm 20x20mm V-slot channel 6mm aluminum profile, for the vertical bars.|
| 4|240mm 20x20mm V-slot channel 6mm aluminum profile, for the side horizontal bars.|
| 4|200mm 20x20mm V-slot channel 6mm aluminum profile, for the front and back horizontal bars.|
|10|160mm 20x20mm V-slot channel 6mm aluminum profile, for the caster and bays supports.|
| 4|"T" connection plate for 20mm profile.|
|12|90 degrees connection plate for 20mm profile.|
|12|90 degrees connection plate for 20mm profile.|
|20|20x20x17mm corner for V-slot or T-slot.|
| 4|Casters 39mm diameter wheel.|
| 80|Allen Bolt M5x6 Cylindrical Head.|
| 56|Allen Bolt M5x6 Flat Head.|
|136|Spring Washer 5mm.|
|128|Hammer Nut M5.|

## Nuts and Bolts

Picture|Description|
|---|---|
|PSU Module|Allen Bolt M5x6 Cylindrical Head (5mm on diameter, 6mm on length)|
|PSU Module|Allen Bolt M5x6 Flat Head (5mm on diameter, 6mm on length)|
|PSU Module|Hammer Nut M5 (for 5mm diameter bolts)|
|PSU Module|Spring Washer 5mm|

## Pictures

Structure (Top, Side)
Structure (Bottom, Side)
Structure (Bottom)
Structure (Bottom, Rear)
Structure (Bottom, Front)
Structure (Caster details)

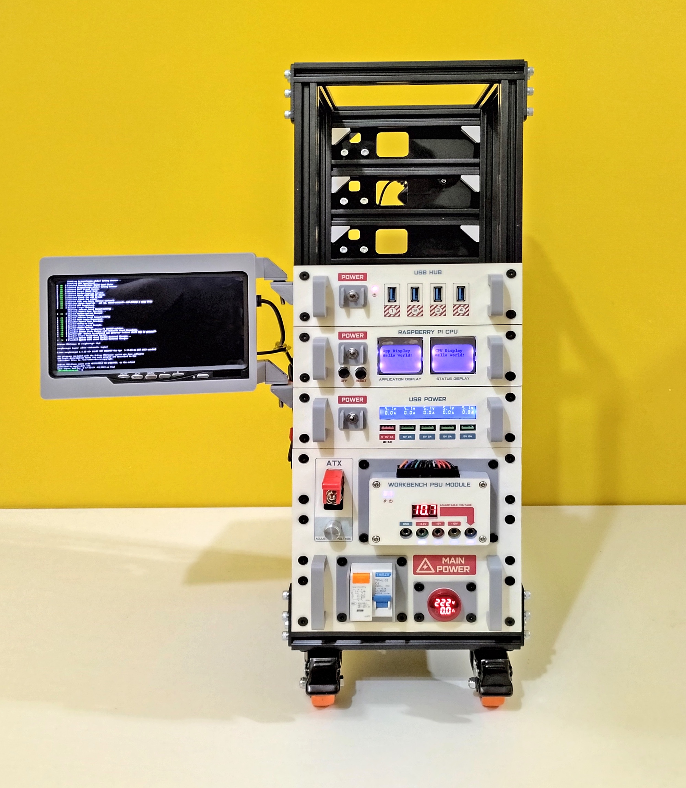
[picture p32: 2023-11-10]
images/pictures/minilab-002.jpg

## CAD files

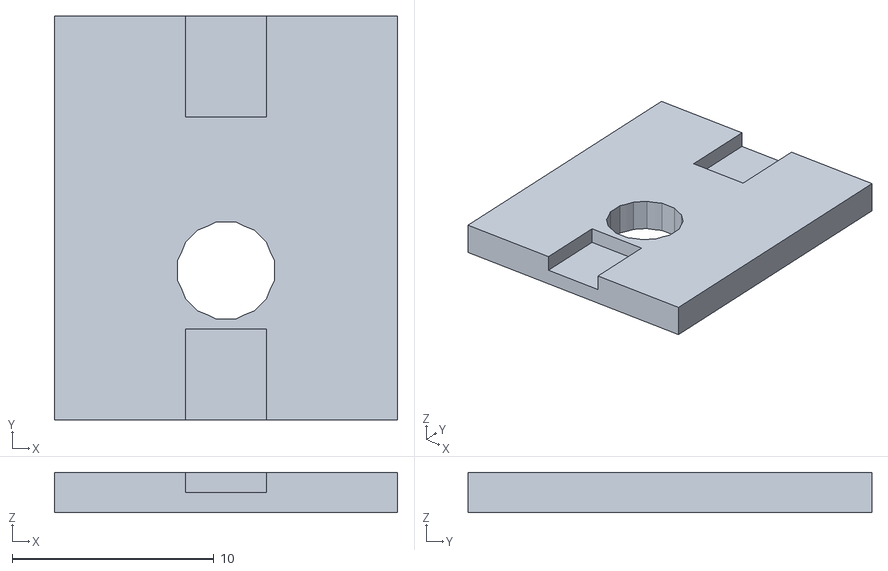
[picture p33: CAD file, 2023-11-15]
3dprint/extra-minilcdmonitor/extra-minilcdmonitor-spacer.stl
17.0 x 20.0 x 2.00

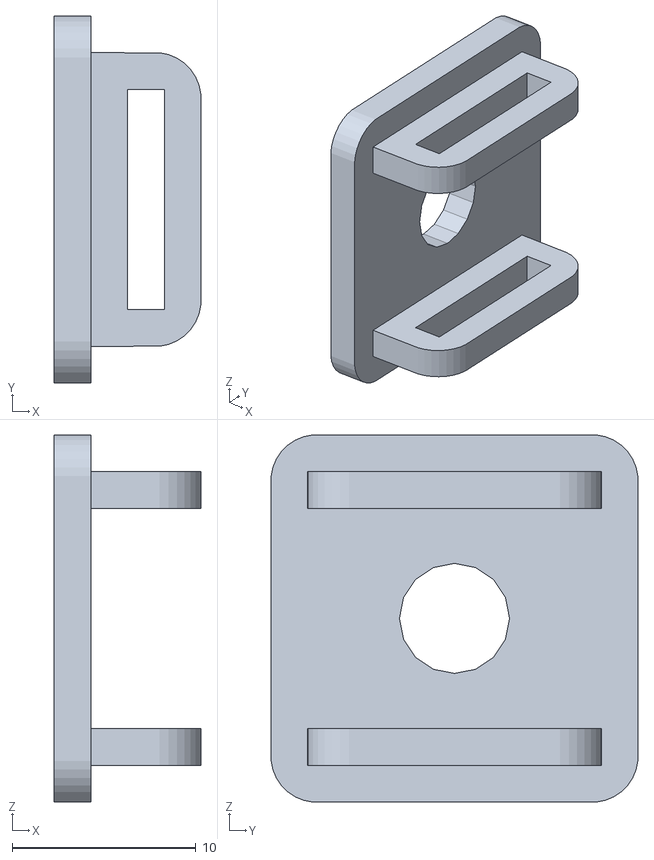
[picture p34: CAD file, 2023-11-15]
3dprint/extra-velcrostrap/extra-velcrostrap.stl
7.99 x 20.0 x 20.0

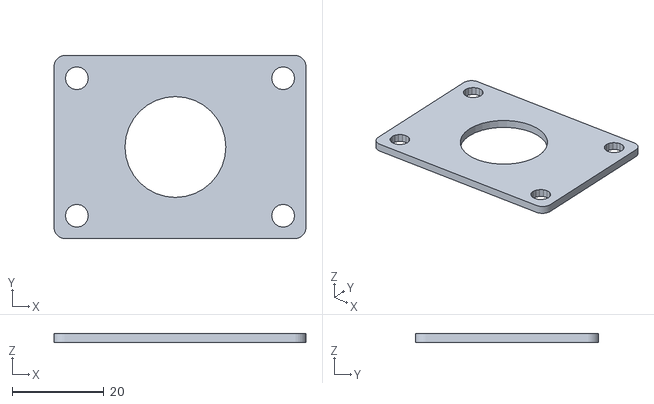
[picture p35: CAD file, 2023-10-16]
3dprint/module-psu/psu.panel.meterpanel.stl
55.0 x 40.0 x 2.00

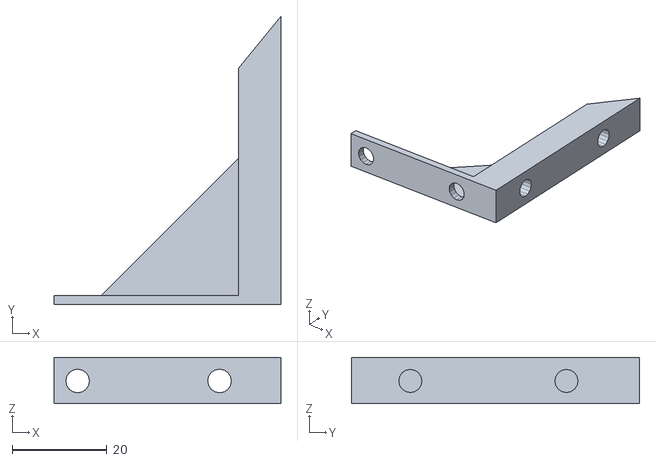
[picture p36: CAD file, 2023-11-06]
3dprint/module-rpicpu/rpicpu.innersupport.left.stl
48.0 x 61.0 x 9.80

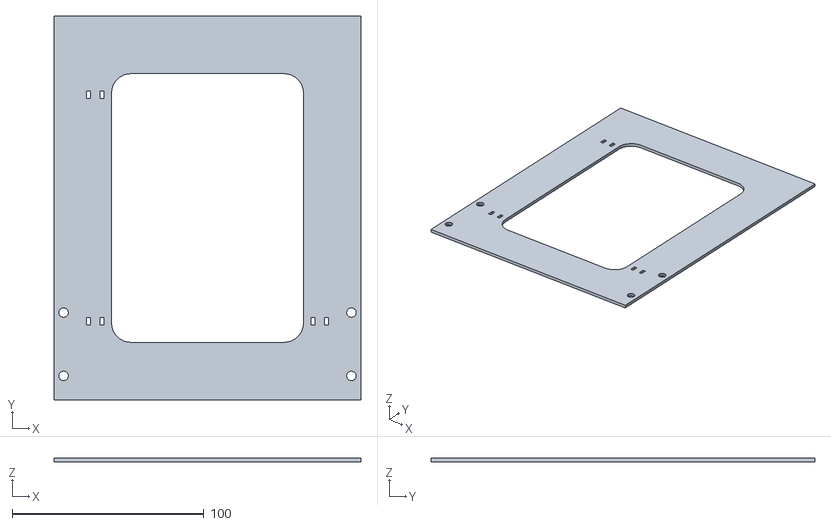
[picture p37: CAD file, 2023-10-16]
3dprint/module-usbhub/usbhub.base.stl
160.0 x 200.0 x 2.00

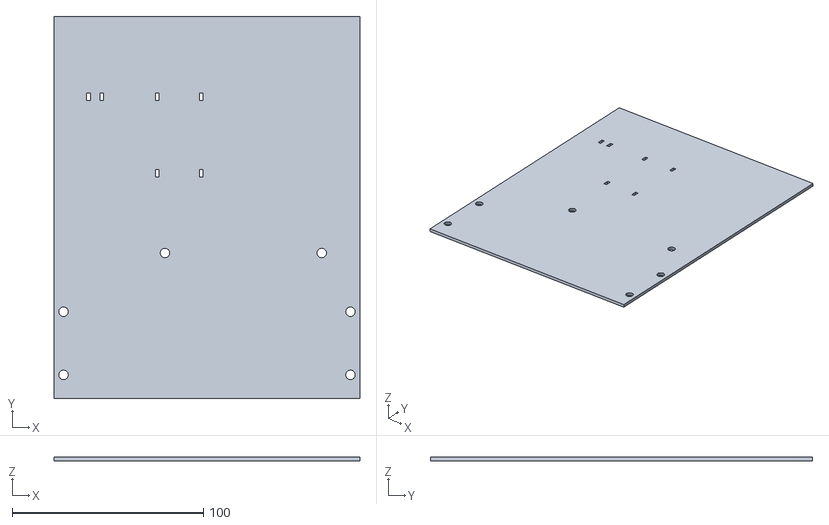
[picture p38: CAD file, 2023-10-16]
3dprint/module-usbpower/usbpower.base.stl
160.0 x 200.0 x 2.00

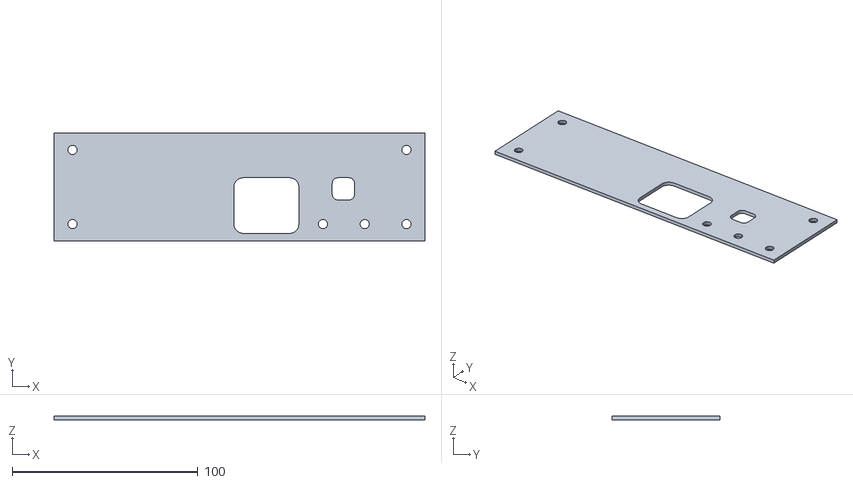
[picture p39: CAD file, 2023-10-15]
3dprint/rear/rear.baycover60mm.stl
200.0 x 58.0 x 2.00

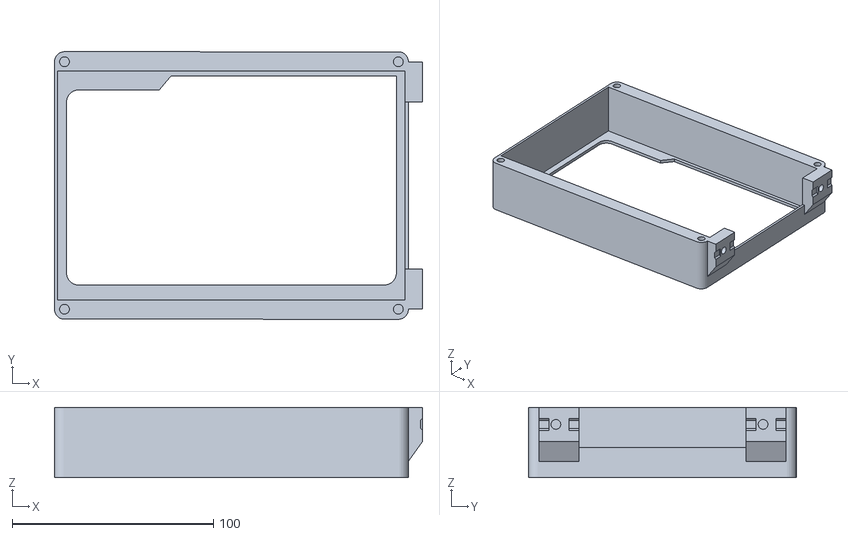
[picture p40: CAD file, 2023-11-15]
3dprint/extra-minilcdmonitor/extra-minilcdmonitor-front.stl
183.0 x 133.0 x 35.0

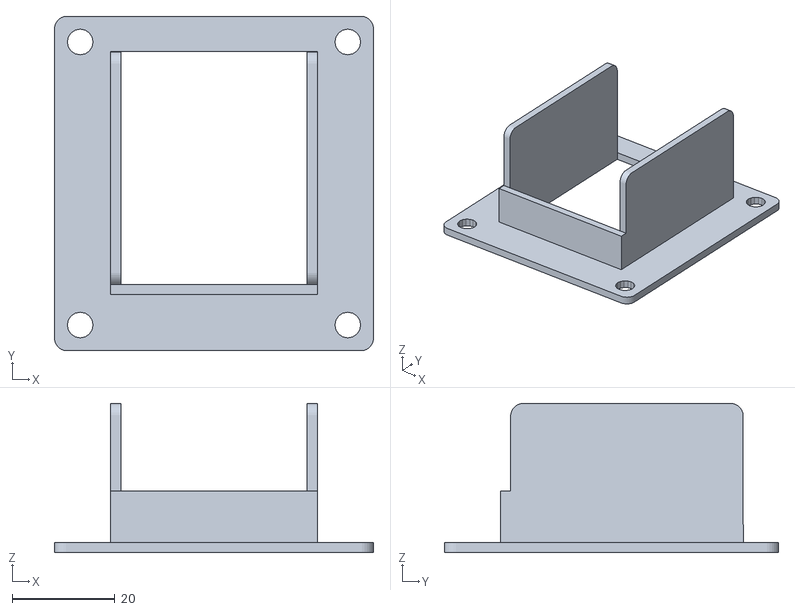
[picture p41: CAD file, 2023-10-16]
3dprint/module-psu/psu.panel.circuitbreakerpanel.stl
62.0 x 65.0 x 29.0

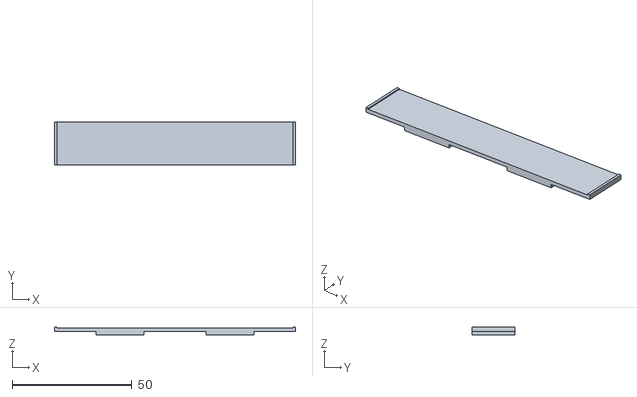
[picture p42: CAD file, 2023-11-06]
3dprint/module-rpicpu/rpicpu.panel.lcdsupport.stl
100.8 x 18.0 x 3.30

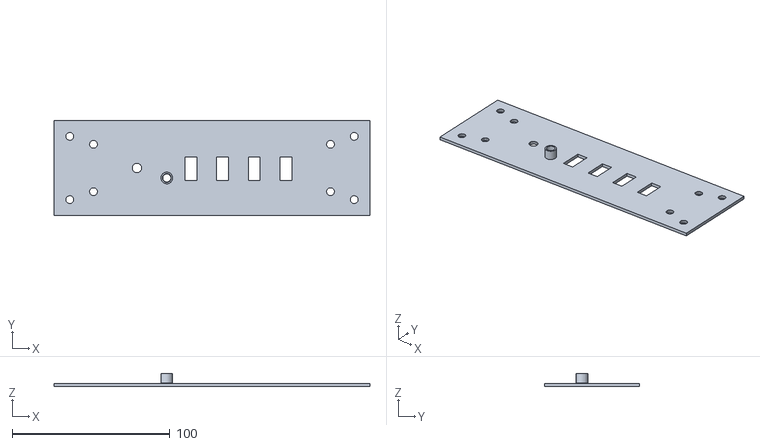
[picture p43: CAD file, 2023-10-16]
3dprint/module-usbhub/usbhub.panel.front.stl
200.0 x 60.0 x 8.20

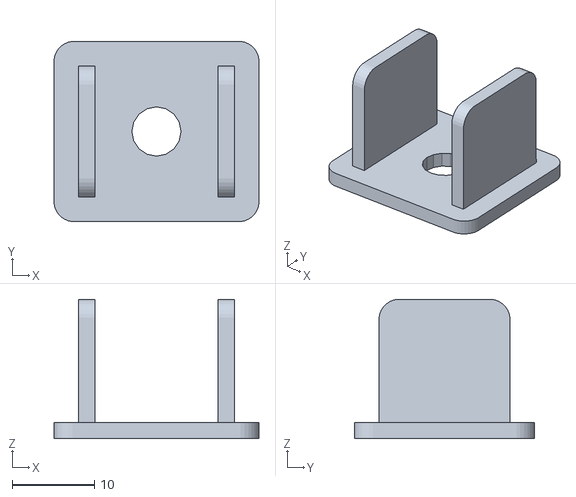
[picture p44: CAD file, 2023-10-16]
3dprint/module-usbpower/usbpower.panel.powerpanel.stl
25.0 x 22.0 x 17.0

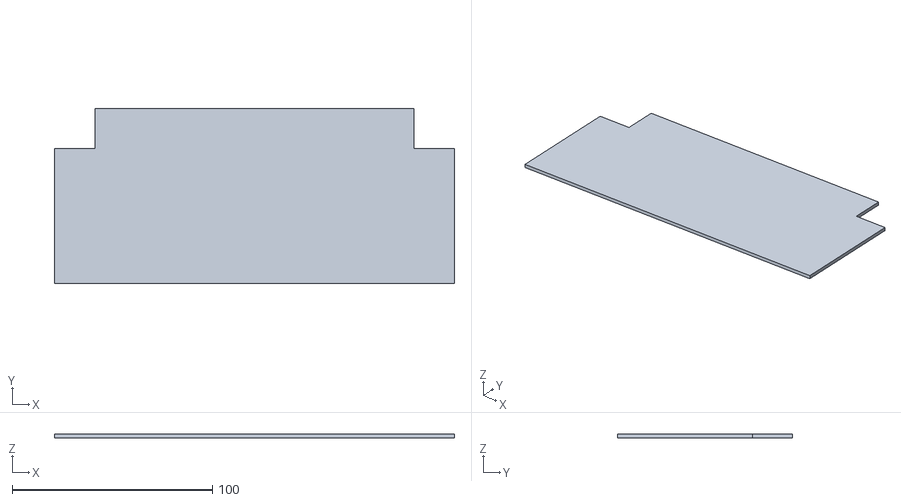
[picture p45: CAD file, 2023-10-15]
3dprint/rear/rear.bottomcover.stl
200.0 x 87.6 x 2.00

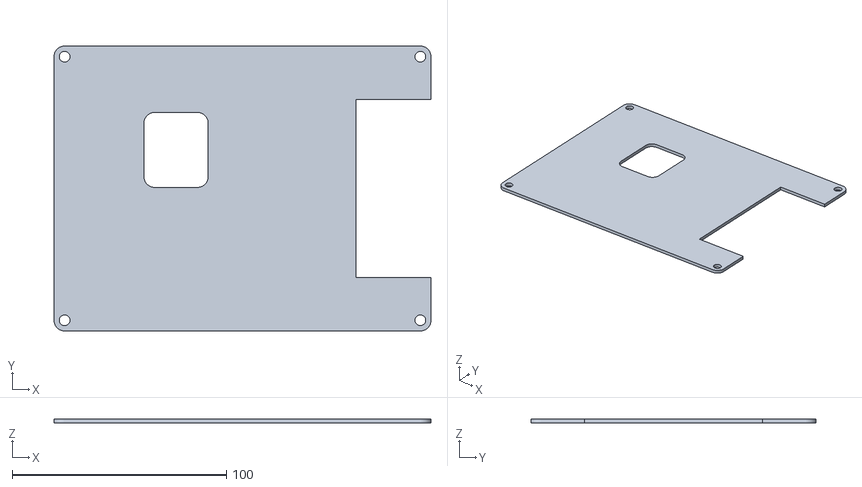
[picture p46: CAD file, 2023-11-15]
3dprint/extra-minilcdmonitor/extra-minilcdmonitor-back.stl
176.0 x 133.0 x 2.00

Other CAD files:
3dprint/module-psu/psu.panel.modulecover2.stl
3dprint/module-rpicpu/rpicpu.innersupport.right.stl
3dprint/module-usbhub/usbhub.innersupport.right.stl
3dprint/module-usbpower/usbpower.panel.front.stl
3dprint/extra-minilcdmonitor/extra-minilcdmonitor-back.blend
3dprint/extra-minilcdmonitor/extra-minilcdmonitor-front.blend
3dprint/extra-minilcdmonitor/extra-minilcdmonitor-spacer.blend
3dprint/extra-velcrostrap/extra-velcrostrap.blend
3dprint/module-psu/psu.base.blend
3dprint/module-psu/psu.base.stl
3dprint/module-psu/psu.cableguide.blend
3dprint/module-psu/psu.cableguide.stl
3dprint/module-psu/psu.circuitbreakersupport.blend
3dprint/module-psu/psu.circuitbreakersupport.stl
3dprint/module-psu/psu.panel.circuitbreakerpanel.blend
3dprint/module-psu/psu.panel.front.blend
3dprint/module-psu/psu.panel.front.stl
3dprint/module-psu/psu.panel.handler.blend
3dprint/module-psu/psu.panel.handler.stl
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

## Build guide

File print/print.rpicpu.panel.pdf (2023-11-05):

## raspberry pi cpu

OFF RESET

## power

application display | status display

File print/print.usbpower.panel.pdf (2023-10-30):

power | usb power
5 - 9V 3A | 5V 2A | 5V 2A | 5V 2A | 5V 2a

QC 3.0

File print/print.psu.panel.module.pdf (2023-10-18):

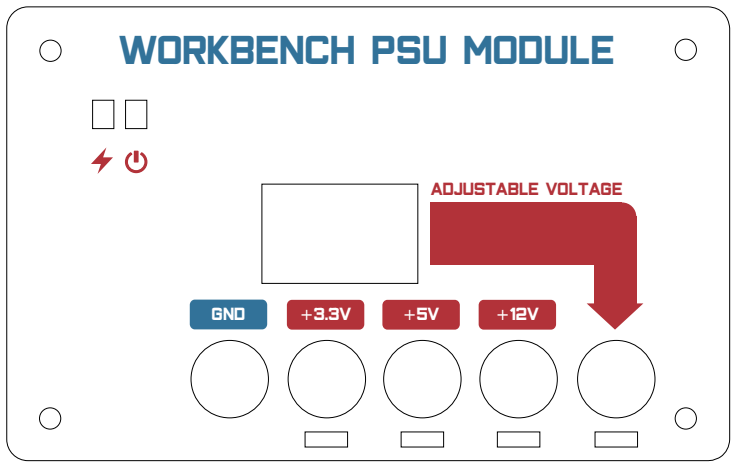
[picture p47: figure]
workbench psu module; ADJUSTABLE VOLTAGE; GND

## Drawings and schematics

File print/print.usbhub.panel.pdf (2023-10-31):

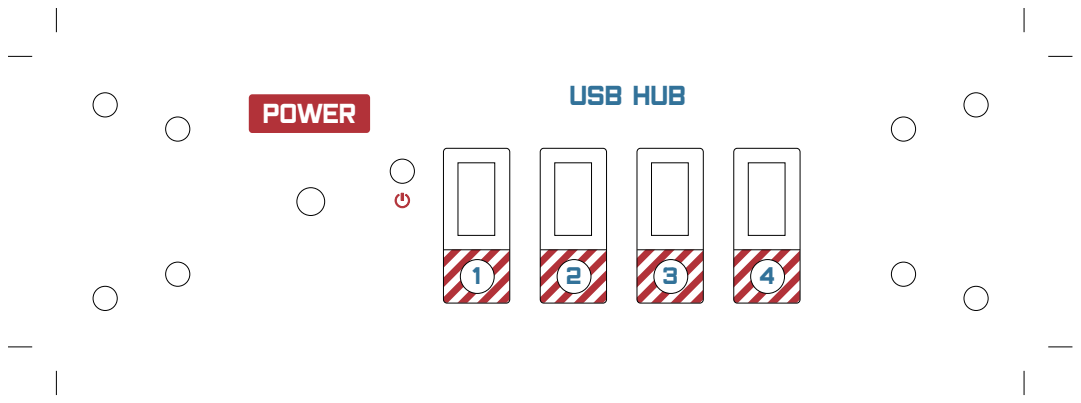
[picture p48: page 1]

usb hub power

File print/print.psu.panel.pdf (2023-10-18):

# ATX

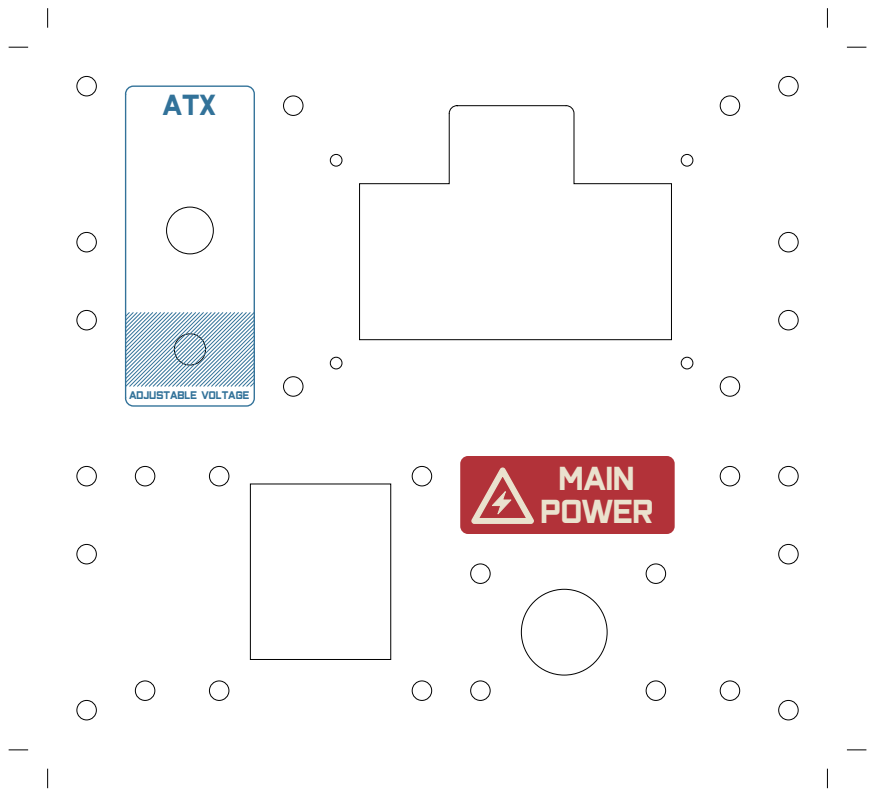
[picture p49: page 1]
main power; adjustable voltage

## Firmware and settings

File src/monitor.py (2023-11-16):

import Adafruit_Nokia_LCD as LCD
import Adafruit_GPIO.SPI as SPI
import RPi.GPIO as gpio
from PIL import Image
from PIL import ImageDraw
from PIL import ImageFont

DISPLAYS_DC = 23
DISPLAY1_RST = 20
DISPLAY2_RST = 21
DISPLAY1_LCD = 1
DISPLAY2_LCD = 25
BTN_RESET = 15
BTN_OFF = 18

display1 = LCD.PCD8544(DISPLAYS_DC, DISPLAY1_RST, spi=SPI.SpiDev(0, 0, max_speed_hz=4000000))
display2 = LCD.PCD8544(DISPLAYS_DC, DISPLAY2_RST, spi=SPI.SpiDev(0, 1, max_speed_hz=4000000))

display1.begin(contrast=40)
display2.begin(contrast=58)

image = Image.new('1', (LCD.LCDWIDTH, LCD.LCDHEIGHT))
draw = ImageDraw.Draw(image)


draw.rectangle((0, 0, LCD.LCDWIDTH, LCD.LCDHEIGHT), outline=255, fill=255)
draw.text ((0,0), 'CPU Display')
draw.text ((0,10), 'Hello World!')

display1.image(image)
display1.display()


draw.rectangle((0, 0, LCD.LCDWIDTH, LCD.LCDHEIGHT), outline=255, fill=255)
draw.text((0,0), 'App Display')
draw.text((0,10), 'Hello World!')

display2.image(image)
display2.display()



gpio.setmode(gpio.BCM)

gpio.setup(BTN_RESET, gpio.IN, pull_up_down = gpio.PUD_DOWN)
gpio.setup(BTN_OFF, gpio.IN, pull_up_down = gpio.PUD_DOWN)

gpio.setup(DISPLAY1_LCD, gpio.OUT)
gpio.setup(DISPLAY2_LCD, gpio.OUT)

gpio.output(DISPLAY1_LCD, 0)
gpio.output(DISPLAY2_LCD, 0)

while (True):
  if gpio.input(BTN_RESET):
    print('RESET')
    call('sudo reboot', shell=True)
    break
  if gpio.input(BTN_OFF):
    print('OFF')
    call('sudo shutdown -h now', shell=True)
    

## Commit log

2023-10-15 Adding 3d print files
    [rear.baycover.psu.blend, rear.baycover.psu.stl, rear.baycover60mm.blend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]
2023-10-16 Adding PSU 3D print files.
    [psu.bottomcover.blend, psu.bottomcover.stl, psu.cableguide.blend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]
2023-10-16 Adding USB Power 3d print files.
    [psu.base.blend, psu.base.stl, usbpower.base.blend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]
2023-10-16 Adding USB Hub 3D print files.
    [usbhub.base.blend, usbhub.base.stl, usbhub.innersupport.left.blend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]
2023-10-16 Adding PSU module schematics
2023-10-17 Updating power module schematics
2023-10-17 Adding 3D print list
2023-10-17 Fixing 3D Printed Parts
2023-10-17 Completed 3d printed parts and shopping list
2023-10-17 Fixing circuit breaker model.
2023-10-18 Adding paper printed files
2023-10-22 Adding rear labels print
2023-10-27 Adding USB Power module details
2023-10-29 Adding Nuts and Bolts info.
2023-10-30 Completing PSU and USB Power modules.
2023-11-05 Addin Raspberry Pi CPU and updating USB Hub
2023-11-06 Updating docs
    [rpicpu.base.blend, rpicpu.base.stl, rpicpu.innersupport.left.blend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]
2023-11-07 Adding USB Hub Schematics
2023-11-10 Fnishing uma porrada de coisa :-P
2023-11-13 Adding Raspberry Pi CPU Schematics
2023-11-15 Finishing everything
    [extra-minilcdmonitor-back.blend, extra-minilcdmonitor-back.stl, extra-minilcdmonitor-front.blend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]
2023-11-16 Fixing file names.
    [module-psu.blend, module-rpicpu.blend, module-usbhub.blend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]
